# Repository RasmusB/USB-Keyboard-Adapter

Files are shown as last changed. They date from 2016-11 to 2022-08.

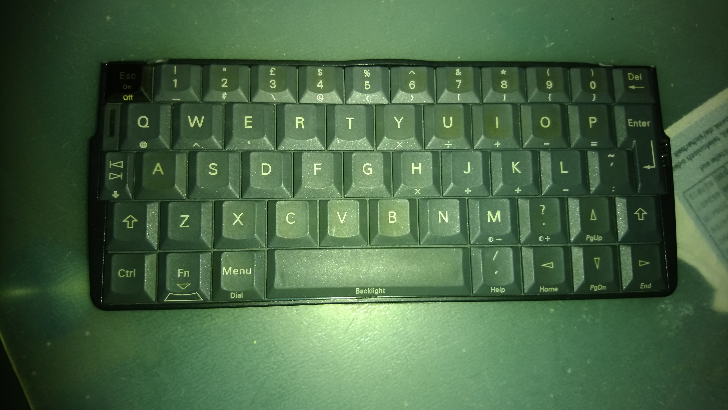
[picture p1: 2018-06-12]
Psion-Keyboard-Firmware/Keymaps/mx5_UK/UK Layout.jpg

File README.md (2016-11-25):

# USB-Keyboard-Adapter

An ATmega32u4 based keyboard controller. This was designed for use with a Psion Series 5mx keyboard, but should work for other keyboards also.

* PCB contains KiCad files for the device itself
* Firmware/Psion-Keyboard-Firmware contains an Arduino sketch for the firmware
* Firmware/ScanTheMatrix is a sketch for scanning the matrix of a keyboard. This is only meant as a tool to map a keyboard with an unknown pinout.

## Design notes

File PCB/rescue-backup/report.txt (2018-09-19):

Info: Backing up file “C:\Users\Rasmus\Dropbox\Projekt\Teknik\USB-Keyboard-Adapter\PCB\sym-lib-table” to file “C:\Users\Rasmus\Dropbox\Projekt\Teknik\USB-Keyboard-Adapter\PCB\rescue-backup\sym-lib-table-2018-09-19-20-54-59”.
Info: Backing up file “C:\Users\Rasmus\Dropbox\Projekt\Teknik\USB-Keyboard-Adapter\PCB\Keyboard.sch” to file “C:\Users\Rasmus\Dropbox\Projekt\Teknik\USB-Keyboard-Adapter\PCB\rescue-backup\Keyboard-2018-09-19-20-54-59.sch”.
Info: Backing up file “C:\Users\Rasmus\Dropbox\Projekt\Teknik\USB-Keyboard-Adapter\PCB\Keyboard.pro” to file “C:\Users\Rasmus\Dropbox\Projekt\Teknik\USB-Keyboard-Adapter\PCB\rescue-backup\Keyboard-2018-09-19-20-54-59.pro”.
Info: Backing up file “C:\Users\Rasmus\Dropbox\Projekt\Teknik\USB-Keyboard-Adapter\PCB\Keyboard-cache.lib” to file “C:\Users\Rasmus\Dropbox\Projekt\Teknik\USB-Keyboard-Adapter\PCB\rescue-backup\Keyboard-cache-2018-09-19-20-54-59.lib”.
Info: Backing up file “C:\Users\Rasmus\Dropbox\Projekt\Teknik\USB-Keyboard-Adapter\PCB\Keyboard-rescue.lib” to file “C:\Users\Rasmus\Dropbox\Projekt\Teknik\USB-Keyboard-Adapter\PCB\rescue-backup\Keyboard-rescue-2018-09-19-20-54-59.lib”.
Info: Backing up file “C:\Users\Rasmus\Dropbox\Projekt\Teknik\USB-Keyboard-Adapter\PCB\Keyboard-rescue.dcm” to file “C:\Users\Rasmus\Dropbox\Projekt\Teknik\USB-Keyboard-Adapter\PCB\rescue-backup\Keyboard-rescue-2018-09-19-20-54-59.dcm”.
Info: Adding library “Keyboard-rescue”, file “${KIPRJMOD}/Keyboard-rescue.lib” to project symbol library table.
Info: Adding library “rbv_adc”, file “C:\Users\Rasmus\Dropbox\Projekt\Teknik\common\kicad-libs\rb-lib\rbv_adc.lib” to project symbol library table.
Info: Adding library “rbv_arduino”, file “C:\Users\Rasmus\Dropbox\Projekt\Teknik\common\kicad-libs\rb-lib\rbv_arduino.lib” to project symbol library table.
Info: Adding library “rbv_beagleBoard”, file “C:\Users\Rasmus\Dropbox\Projekt\Teknik\common\kicad-libs\rb-lib\rbv_beagleBoard.lib” to project symbol library table.
Info: Adding library “rbv_connectors”, file “C:\Users\Rasmus\Dropbox\Projekt\Teknik\common\kicad-libs\rb-lib\rbv_connectors.lib” to project symbol library table.
Info: Adding library “rbv_conversion”, file “C:\Users\Rasmus\Dropbox\Projekt\Teknik\common\kicad-libs\rb-lib\rbv_conversion.lib” to project symbol library table.
Info: Adding library “rbv_dac”, file “C:\Users\Rasmus\Dropbox\Projekt\Teknik\common\kicad-libs\rb-lib\rbv_dac.lib” to project symbol library table.
Info: Adding library “rbv_device”, file “C:\Users\Rasmus\Dropbox\Projekt\Teknik\common\kicad-libs\rb-lib\rbv_device.lib” to project symbol library table.
Info: Adding library “rbv_diodes”, file “C:\Users\Rasmus\Dropbox\Projekt\Teknik\common\kicad-libs\rb-lib\rbv_diodes.lib” to project symbol library table.
Info: Adding library “rbv_display”, file “C:\Users\Rasmus\Dropbox\Projekt\Teknik\common\kicad-libs\rb-lib\rbv_display.lib” to project symbol library table.
Info: Adding library “rbv_drivers”, file “C:\Users\Rasmus\Dropbox\Projekt\Teknik\common\kicad-libs\rb-lib\rbv_drivers.lib” to project symbol library table.
Info: Adding library “rbv_ecu”, file “C:\Users\Rasmus\Dropbox\Projekt\Teknik\common\kicad-libs\rb-lib\rbv_ecu.lib” to project symbol library table.
Info: Adding library “rbv_fpga”, file “C:\Users\Rasmus\Dropbox\Projekt\Teknik\common\kicad-libs\rb-lib\rbv_fpga.lib” to project symbol library table.
Info: Adding library “rbv_freescale”, file “C:\Users\Rasmus\Dropbox\Projekt\Teknik\common\kicad-libs\rb-lib\rbv_freescale.lib” to project symbol library table.
Info: Adding library “rbv_gps”, file “C:\Users\Rasmus\Dropbox\Projekt\Teknik\common\kicad-libs\rb-lib\rbv_gps.lib” to project symbol library table.
Info: Adding library “rbv_gumstix”, file “C:\Users\Rasmus\Dropbox\Projekt\Teknik\common\kicad-libs\rb-lib\rbv_gumstix.lib” to project symbol library table.
Info: Adding library “rbv_intel”, file “C:\Users\Rasmus\Dropbox\Projekt\Teknik\common\kicad-libs\rb-lib\rbv_intel.lib” to project symbol library table.
Info: Adding library “rbv_interface”, file “C:\Users\Rasmus\Dropbox\Projekt\Teknik\common\kicad-libs\rb-lib\rbv_interface.lib” to project symbol library table.
Info: Adding library “rbv_linear”, file “C:\Users\Rasmus\Dropbox\Projekt\Teknik\common\kicad-libs\rb-lib\rbv_linear.lib” to project symbol library table.
Info: Adding library “rbv_logic”, file “C:\Users\Rasmus\Dropbox\Projekt\Teknik\common\kicad-libs\rb-lib\rbv_logic.lib” to project symbol library table.
Info: Adding library “rbv_logos”, file “C:\Users\Rasmus\Dropbox\Projekt\Teknik\common\kicad-libs\rb-lib\rbv_logos.lib” to project symbol library table.
Info: Adding library “rbv_mcu”, file “C:\Users\Rasmus\Dropbox\Projekt\Teknik\common\kicad-libs\rb-lib\rbv_mcu.lib” to project symbol library table.
Info: Adding library “rbv_memory”, file “C:\Users\Rasmus\Dropbox\Projekt\Teknik\common\kicad-libs\rb-lib\rbv_memory.lib” to project symbol library table.
Info: Adding library “rbv_mosfet”, file “C:\Users\Rasmus\Dropbox\Projekt\Teknik\common\kicad-libs\rb-lib\rbv_mosfet.lib” to project symbol library table.
Info: Adding library “rbv_pcb_extras”, file “C:\Users\Rasmus\Dropbox\Projekt\Teknik\common\kicad-libs\rb-lib\rbv_pcb_extras.lib” to project symbol library table.
Info: Adding library “rbv_power”, file “C:\Users\Rasmus\Dropbox\Projekt\Teknik\common\kicad-libs\rb-lib\rbv_power.lib” to project symbol library table.
Info: Adding library “rbv_ref”, file “C:\Users\Rasmus\Dropbox\Projekt\Teknik\common\kicad-libs\rb-lib\rbv_ref.lib” to project symbol library table.
Info: Adding library “rbv_regul”, file “C:\Users\Rasmus\Dropbox\Projekt\Teknik\common\kicad-libs\rb-lib\rbv_regul.lib” to project symbol library table.
Info: Adding library “rbv_rpi”, file “C:\Users\Rasmus\Dropbox\Projekt\Teknik\common\kicad-libs\rb-lib\rbv_rpi.lib” to project symbol library table.
Info: Adding library “rbv_sensors”, file “C:\Users\Rasmus\Dropbox\Projekt\Teknik\common\kicad-libs\rb-lib\rbv_sensors.lib” to project symbol library table.
Info: Adding library “rbv_switches”, file “C:\Users\Rasmus\Dropbox\Projekt\Teknik\common\kicad-libs\rb-lib\rbv_switches.lib” to project symbol library table.
Info: Adding library “rbv_temp”, file “C:\Users\Rasmus\Dropbox\Projekt\Teknik\common\kicad-libs\rb-lib\rbv_temp.lib” to project symbol library table.
Info: Adding library “rbv_transistor”, file “C:\Users\Rasmus\Dropbox\Projekt\Teknik\common\kicad-libs\rb-lib\rbv_transistor.lib” to project symbol library table.
Info: Adding library “rbv_keyboard”, file “C:\Users\Rasmus\Dropbox\Projekt\Teknik\common\kicad-libs\rb-lib\rbv_keyboard.lib” to project symbol library table.
Info: Adding library “transistors”, file “${KICAD_SYMBOL_DIR}/transistors.lib” to project symbol library table.
Info: Adding library “conn”, file “${KICAD_SYMBOL_DIR}/conn.lib” to project symbol library table.
Info: Adding library “linear”, file “${KICAD_SYMBOL_DIR}/linear.lib” to project symbol library table.
Info: Adding library “regul”, file “${KICAD_SYMBOL_DIR}/regul.lib” to project symbol library table.
Info: Adding library “cmos4000”, file “${KICAD_SYMBOL_DIR}/cmos4000.lib” to project symbol library table.
Info: Adding library “adc-dac”, file “${KICAD_SYMBOL_DIR}/adc-dac.lib” to project symbol library table.
Info: Adding library “memory”, file “${KICAD_SYMBOL_DIR}/memory.lib” to project symbol library table.
Info: Adding library “xilinx”, file “${KICAD_SYMBOL_DIR}/xilinx.lib” to project symbol library table.
Info: Adding library “microcontrollers”, file “${KICAD_SYMBOL_DIR}/microcontrollers.lib” to project symbol library table.
Info: Adding library “dsp”, file “${KICAD_SYMBOL_DIR}/dsp.lib” to project symbol library table.
Info: Adding library “microchip”, file “${KICAD_SYMBOL_DIR}/microchip.lib” to project symbol library table.
Info: Adding library “analog_switches”, file “${KICAD_SYMBOL_DIR}/analog_switches.lib” to project symbol library table.
Info: Adding library “motorola”, file “${KICAD_SYMBOL_DIR}/motorola.lib” to project symbol library table.
Info: Adding library “texas”, file “${KICAD_SYMBOL_DIR}/texas.lib” to project symbol library table.
Info: Adding library “intel”, file “${KICAD_SYMBOL_DIR}/intel.lib” to project symbol library table.
Info: Adding library “digital-audio”, file “${KICAD_SYMBOL_DIR}/digital-audio.lib” to project symbol library table.
Info: Adding library “philips”, file “${KICAD_SYMBOL_DIR}/philips.lib” to project symbol library table.
Info: Adding library “display”, file “${KICAD_SYMBOL_DIR}/display.lib” to project symbol library table.
Info: Adding library “cypress”, file “${KICAD_SYMBOL_DIR}/cypress.lib” to project symbol library table.
Info: Adding library “siliconi”, file “${KICAD_SYMBOL_DIR}/siliconi.lib” to project symbol library table.
Info: Adding library “opto”, file “${KICAD_SYMBOL_DIR}/opto.lib” to project symbol library table.
Info: Adding library “atmel”, file “${KICAD_SYMBOL_DIR}/atmel.lib” to project symbol library table.
Info: Adding library “contrib”, file “${KICAD_SYMBOL_DIR}/contrib.lib” to project symbol library table.
Info: Adding library “valves”, file “${KICAD_SYMBOL_DIR}/valves.lib” to project symbol library table.
Symbol “KEYBOARD-PSION-5MX” mapped to symbol library “rbv_keyboard”.
Symbol “ATMEGA32U4-QFN44” mapped to symbol library “rbv_mcu”.
Symbol “+5V” mapped to symbol library “power”.
Symbol “GND” mapped to symbol library “power”.
Symbol “C” mapped to symbol library “Device”.
Symbol “C” mapped to symbol library “Device”.
Symbol “C” mapped to symbol library “Device”.
Symbol “C” mapped to symbol library “Device”.
Symbol “C” mapped to symbol library “Device”.
Symbol “C” mapped to symbol library “Device”.
Symbol “+5V” mapped to symbol library “power”.
Symbol “+5V” mapped to symbol library “power”.
Symbol “+5V” mapped to symbol library “power”.
Symbol “GND” mapped to symbol library “power”.
Symbol “C” mapped to symbol library “Device”.
Symbol “C” mapped to symbol library “Device”.
Symbol “GND” mapped to symbol library “power”.
Symbol “CRYSTAL-4pin” mapped to symbol library “rbv_device”.
Symbol “C” mapped to symbol library “Device”.
Symbol “C” mapped to symbol library “Device”.
Symbol “GND” mapped to symbol library “power”.
Symbol “GND” mapped to symbol library “power”.
Symbol “C” mapped to symbol library “Device”.
Symbol “R” mapped to symbol library “Device”.
Symbol “R” mapped to symbol library “Device”.
Symbol “+5V” mapped to symbol library “power”.
Symbol “R” mapped to symbol library “Device”.
Symbol “+5V” mapped to symbol library “power”.
Symbol “ATMEL_ISP-6P” mapped to symbol library “rbv_mcu”.
Symbol “+5V” mapped to symbol library “power”.
Symbol “GND” mapped to symbol library “power”.
Symbol “USB_OTG-RESCUE-Keyboard” mapped to symbol library “Keyboard-rescue”.
Symbol “R” mapped to symbol library “Device”.
Symbol “C” mapped to symbol library “Device”.
Symbol “GNDPWR” mapped to symbol library “Keyboard-rescue”.
Symbol “Led_Small” mapped to symbol library “Keyboard-rescue”.
Symbol “R_Small” mapped to symbol library “Device”.
Symbol “GND” mapped to symbol library “power”.
Symbol “SW_PUSH” mapped to symbol library “Keyboard-rescue”.
Symbol “GND” mapped to symbol library “power”.
Symbol “GND” mapped to symbol library “power”.
Symbol “VBUS” mapped to symbol library “rbv_power”.
Symbol “F_Small” mapped to symbol library “Keyboard-rescue”.
Info: Symbol library table mapping complete!

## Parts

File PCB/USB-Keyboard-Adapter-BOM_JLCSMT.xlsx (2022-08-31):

Comment | Designator | Footprint | JLCPCB Part #（optional）
1µF | C1, C9 | C_0402 | C52923
100nF | C2, C3, C4, C5, C6, C7, C8 | C_0402 | C1525
6.2pF | C10, C11 | C_0402 | C325456
4.7nF | C12 | C_0402 | C1538
STATUS LED | D1 | LED_0402 | C965790
500mA Polyfuse | F1 | FUSE_0603 | C207017
22p FPC connector | KB1 | 22p FPC | C262275
USB Micro B | P1 | USB Micro B | C132563
10k | R1 | R_0402 | C25744
22R | R2, R3 | R_0402 | C25092
1M | R4 | R_0402 | C26083
1k | R5 | R_0402 | C11702
RESET BUTTON | SW1 | Switch | C115358
ATMEGA32U4-MU | U1 | QFN44 | C112161
16MHz | Y1 | 2.5x2.0mm 4pin | C1986789

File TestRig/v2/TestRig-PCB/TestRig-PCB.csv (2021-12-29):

Reference | Value | Footprint | Datasheet | MPN | Manufacturer
MOD101 | STM32_BLUE_PILL | BluePill:STM32F103C8T6-ARM-BOARD
J101 | AVR-ISP-6 | Connector_IDC:IDC-Header_2x03_P2.54mm_Vertical | ~ | 87834-0619 | Molex
J102 | AVR-ISP-10 | Connector_IDC:IDC-Header_2x05_P2.54mm_Vertical | ~ | 70246-1001 | Molex
R102 | 4k7 | Resistor_SMD:R_0603_1608Metric | ~ | CR0603-JW-472ELF | Bourns
R101 | 4k7 | Resistor_SMD:R_0603_1608Metric | ~ | CR0603-JW-472ELF | Bourns
R103 | 10k | Resistor_SMD:R_0603_1608Metric | ~ | CR0603-JW-103ELF | Bourns
R104 | 10k | Resistor_SMD:R_0603_1608Metric | ~ | CR0603-JW-103ELF | Bourns
H101 | M3 | MountingHole:MountingHole_3.2mm_M3 | ~
H102 | M3 | MountingHole:MountingHole_3.2mm_M3 | ~
H103 | M3 | MountingHole:MountingHole_3.2mm_M3 | ~
H104 | M3 | MountingHole:MountingHole_3.2mm_M3 | ~
H105 | M3 | MountingHole:MountingHole_3.2mm_M3 | ~
H106 | M3 | MountingHole:MountingHole_3.2mm_M3 | ~
JIG_OUTLINE_1 | TEST_JIG | USB-Keyboard:TestJig
REG101 | eC_REG | PCB Extras:eC-Registration
REG102 | eC_REG | PCB Extras:eC-Registration
TP206 | VBUS | Pogo:Pogo_P50_Bottom | ~
TP207 | GND | Pogo:Pogo_P50_Bottom | ~
TP201 | RESET | Pogo:Pogo_P50_Bottom | ~
TP202 | SCK | Pogo:Pogo_P50_Bottom | ~
TP204 | MISO | Pogo:Pogo_P50_Bottom | ~
TP203 | MOSI | Pogo:Pogo_P50_Bottom | ~
R201 | 10k 0.1% | Resistor_SMD:R_0603_1608Metric | ~ | ERA-3AEB103V | Panasonic
R202 | 10k 0.1% | Resistor_SMD:R_0603_1608Metric | ~ | ERA-3AEB103V | Panasonic
DUT201 | DUT_OUTLINE | USB-Keyboard:USB_KEYBOARD_ADAPTER_V1.22_DUMMY
TP205 | VTARGET | Pogo:Pogo_P50_Bottom | ~
J201 | DUT_CONN | Connector_FFC-FPC:Hirose_FH12-22S-0.5SH_1x22-1MP_P0.50mm_Horizontal |  | FH12A-22S-0.5SH(55) | Hirose
C201 | 100n | Capacitor_SMD:C_0603_1608Metric | ~ | C0603C104Z3VACTU | KEMET
U201 | TCA6424A | Package_DFN_QFN:QFN-32-1EP_5x5mm_P0.5mm_EP3.1x3.1mm | https://www.ti.com/lit/gpn/tca6424a | TCA6424ARGJR | Texas Instruments
C202 | 100n | Capacitor_SMD:C_0603_1608Metric | ~ | C0603C104Z3VACTU | KEMET
R203 | 4k7 | Resistor_SMD:R_0603_1608Metric | ~ | CR0603-JW-472ELF | Bourns
R204 | 270R | Resistor_SMD:R_0603_1608Metric |  | CRGCQ0603F270R | TE Connecitivity
LED201 | RED | LED_SMD:LED_0603_1608Metric | https://datasheet.octopart.com/APT1608SRCPRV-Kingbright-datasheet-12598008.pdf | APT1608SRCPRV | Kingbright
R205 | 270R | Resistor_SMD:R_0603_1608Metric |  | CRGCQ0603F270R | TE Connecitivity
LED202 | ORNG | LED_SMD:LED_0603_1608Metric | https://datasheet.octopart.com/APT1608SECK-Kingbright-datasheet-8326367.pdf | APT1608SECK | Kingbright
R206 | 270R | Resistor_SMD:R_0603_1608Metric |  | CRGCQ0603F270R | TE Connecitivity
LED203 | YLW | LED_SMD:LED_0603_1608Metric | https://datasheet.octopart.com/APT1608SYCK-Kingbright-datasheet-108048836.pdf | APT1608SYCK | Kingbright
R207 | 270R | Resistor_SMD:R_0603_1608Metric |  | CRGCQ0603F270R | TE Connecitivity
LED204 | GRN | LED_SMD:LED_0603_1608Metric | https://datasheet.octopart.com/APT1608CGCK-Kingbright-datasheet-12518645.pdf | APT1608CGCK | Kingbright
U301 | TS5A3357 | Package_SO:VSSOP-8_2.3x2mm_P0.5mm | https://www.ti.com/lit/ds/symlink/ts5a3357.pdf | TS5A3357DCUR | Texas Instruments
C302 | 100n | Capacitor_SMD:C_0603_1608Metric | ~ | C0603C104Z3VACTU | KEMET
C303 | 100n | Capacitor_SMD:C_0603_1608Metric | ~ | C0603C104Z3VACTU | KEMET
C304 | 100n | Capacitor_SMD:C_0603_1608Metric | ~ | C0603C104Z3VACTU | KEMET
C305 | 100n | Capacitor_SMD:C_0603_1608Metric | ~ | C0603C104Z3VACTU | KEMET
U302 | TS5A3357 | Package_SO:VSSOP-8_2.3x2mm_P0.5mm | https://www.ti.com/lit/ds/symlink/ts5a3357.pdf | TS5A3357DCUR | Texas Instruments
U303 | TS5A3357 | Package_SO:VSSOP-8_2.3x2mm_P0.5mm | https://www.ti.com/lit/ds/symlink/ts5a3357.pdf | TS5A3357DCUR | Texas Instruments
U304 | TS5A3357 | Package_SO:VSSOP-8_2.3x2mm_P0.5mm | https://www.ti.com/lit/ds/symlink/ts5a3357.pdf | TS5A3357DCUR | Texas Instruments
U305 | TS5A3357 | Package_SO:VSSOP-8_2.3x2mm_P0.5mm | https://www.ti.com/lit/ds/symlink/ts5a3357.pdf | TS5A3357DCUR | Texas Instruments
C301 | 100n | Capacitor_SMD:C_0603_1608Metric | ~ | C0603C104Z3VACTU | KEMET
TP406 | VBUS | Pogo:Pogo_P50_Bottom | ~
TP407 | GND | Pogo:Pogo_P50_Bottom | ~
TP401 | RESET | Pogo:Pogo_P50_Bottom | ~
TP402 | SCK | Pogo:Pogo_P50_Bottom | ~
TP404 | MISO | Pogo:Pogo_P50_Bottom | ~
TP403 | MOSI | Pogo:Pogo_P50_Bottom | ~
R401 | 10k 0.1% | Resistor_SMD:R_0603_1608Metric | ~ | ERA-3AEB103V | Panasonic
R402 | 10k 0.1% | Resistor_SMD:R_0603_1608Metric | ~ | ERA-3AEB103V | Panasonic
DUT401 | DUT_OUTLINE | USB-Keyboard:USB_KEYBOARD_ADAPTER_V1.22_DUMMY
TP405 | VTARGET | Pogo:Pogo_P50_Bottom | ~
J401 | DUT_CONN | Connector_FFC-FPC:Hirose_FH12-22S-0.5SH_1x22-1MP_P0.50mm_Horizontal |  | FH12A-22S-0.5SH(55) | Hirose
C401 | 100n | Capacitor_SMD:C_0603_1608Metric | ~ | C0603C104Z3VACTU | KEMET
U401 | TCA6424A | Package_DFN_QFN:QFN-32-1EP_5x5mm_P0.5mm_EP3.1x3.1mm | https://www.ti.com/lit/gpn/tca6424a | TCA6424ARGJR | Texas Instruments
C402 | 100n | Capacitor_SMD:C_0603_1608Metric | ~ | C0603C104Z3VACTU | KEMET
R403 | 4k7 | Resistor_SMD:R_0603_1608Metric | ~ | CR0603-JW-472ELF | Bourns
R404 | 270R | Resistor_SMD:R_0603_1608Metric |  | CRGCQ0603F270R | TE Connecitivity
LED401 | RED | LED_SMD:LED_0603_1608Metric | https://datasheet.octopart.com/APT1608SRCPRV-Kingbright-datasheet-12598008.pdf | APT1608SRCPRV | Kingbright
R405 | 270R | Resistor_SMD:R_0603_1608Metric |  | CRGCQ0603F270R | TE Connecitivity
LED402 | ORNG | LED_SMD:LED_0603_1608Metric | https://datasheet.octopart.com/APT1608SECK-Kingbright-datasheet-8326367.pdf | APT1608SECK | Kingbright
R406 | 270R | Resistor_SMD:R_0603_1608Metric |  | CRGCQ0603F270R | TE Connecitivity
LED403 | YLW | LED_SMD:LED_0603_1608Metric | https://datasheet.octopart.com/APT1608SYCK-Kingbright-datasheet-108048836.pdf | APT1608SYCK | Kingbright
R407 | 270R | Resistor_SMD:R_0603_1608Metric |  | CRGCQ0603F270R | TE Connecitivity
LED404 | GRN | LED_SMD:LED_0603_1608Metric | https://datasheet.octopart.com/APT1608CGCK-Kingbright-datasheet-12518645.pdf | APT1608CGCK | Kingbright
TP506 | VBUS | Pogo:Pogo_P50_Bottom | ~
TP507 | GND | Pogo:Pogo_P50_Bottom | ~
TP501 | RESET | Pogo:Pogo_P50_Bottom | ~
TP502 | SCK | Pogo:Pogo_P50_Bottom | ~
TP504 | MISO | Pogo:Pogo_P50_Bottom | ~
TP503 | MOSI | Pogo:Pogo_P50_Bottom | ~
R501 | 10k 0.1% | Resistor_SMD:R_0603_1608Metric | ~ | ERA-3AEB103V | Panasonic
R502 | 10k 0.1% | Resistor_SMD:R_0603_1608Metric | ~ | ERA-3AEB103V | Panasonic
DUT501 | DUT_OUTLINE | USB-Keyboard:USB_KEYBOARD_ADAPTER_V1.22_DUMMY
TP505 | VTARGET | Pogo:Pogo_P50_Bottom | ~
J501 | DUT_CONN | Connector_FFC-FPC:Hirose_FH12-22S-0.5SH_1x22-1MP_P0.50mm_Horizontal |  | FH12A-22S-0.5SH(55) | Hirose
C501 | 100n | Capacitor_SMD:C_0603_1608Metric | ~ | C0603C104Z3VACTU | KEMET
U501 | TCA6424A | Package_DFN_QFN:QFN-32-1EP_5x5mm_P0.5mm_EP3.1x3.1mm | https://www.ti.com/lit/gpn/tca6424a | TCA6424ARGJR | Texas Instruments
C502 | 100n | Capacitor_SMD:C_0603_1608Metric | ~ | C0603C104Z3VACTU | KEMET
R503 | 4k7 | Resistor_SMD:R_0603_1608Metric | ~ | CR0603-JW-472ELF | Bourns
R504 | 270R | Resistor_SMD:R_0603_1608Metric |  | CRGCQ0603F270R | TE Connecitivity
LED501 | RED | LED_SMD:LED_0603_1608Metric | https://datasheet.octopart.com/APT1608SRCPRV-Kingbright-datasheet-12598008.pdf | APT1608SRCPRV | Kingbright
R505 | 270R | Resistor_SMD:R_0603_1608Metric |  | CRGCQ0603F270R | TE Connecitivity
LED502 | ORNG | LED_SMD:LED_0603_1608Metric | https://datasheet.octopart.com/APT1608SECK-Kingbright-datasheet-8326367.pdf | APT1608SECK | Kingbright
R506 | 270R | Resistor_SMD:R_0603_1608Metric |  | CRGCQ0603F270R | TE Connecitivity
LED503 | YLW | LED_SMD:LED_0603_1608Metric | https://datasheet.octopart.com/APT1608SYCK-Kingbright-datasheet-108048836.pdf | APT1608SYCK | Kingbright
R507 | 270R | Resistor_SMD:R_0603_1608Metric |  | CRGCQ0603F270R | TE Connecitivity
LED504 | GRN | LED_SMD:LED_0603_1608Metric | https://datasheet.octopart.com/APT1608CGCK-Kingbright-datasheet-12518645.pdf | APT1608CGCK | Kingbright

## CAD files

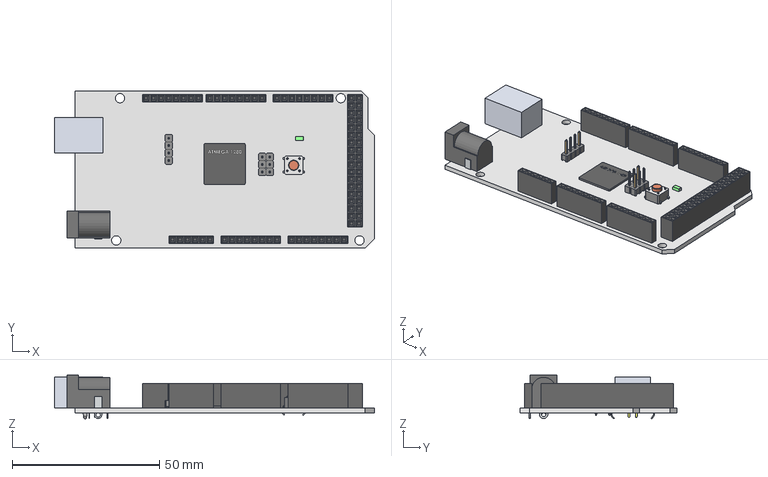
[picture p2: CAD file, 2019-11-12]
TestRig/v2/TestRig-PCB/Footprints/STEP/ArduinoMega2560R3.step
108.6 x 53.2 x 14.9 mm

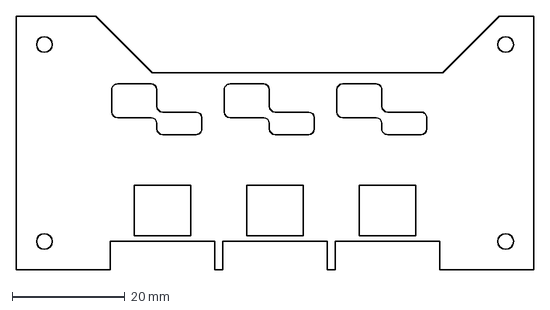
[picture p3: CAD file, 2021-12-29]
TestRig/v2/TestRig-PCB/Footprints/Test Jig v12 outline.dxf
92.0 x 45.0 mm

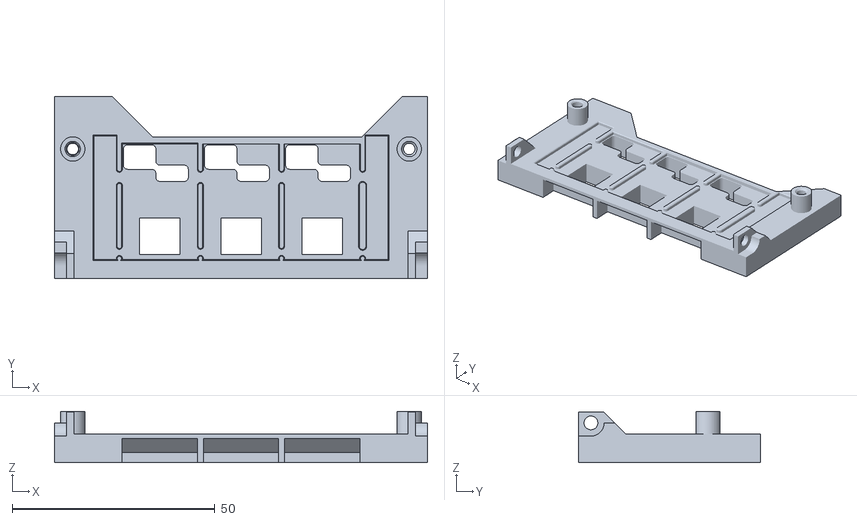
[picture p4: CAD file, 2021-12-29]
TestRig/v2/TestRig-PCB/Test Jig Base v10.stl
92.0 x 45.0 x 12.6

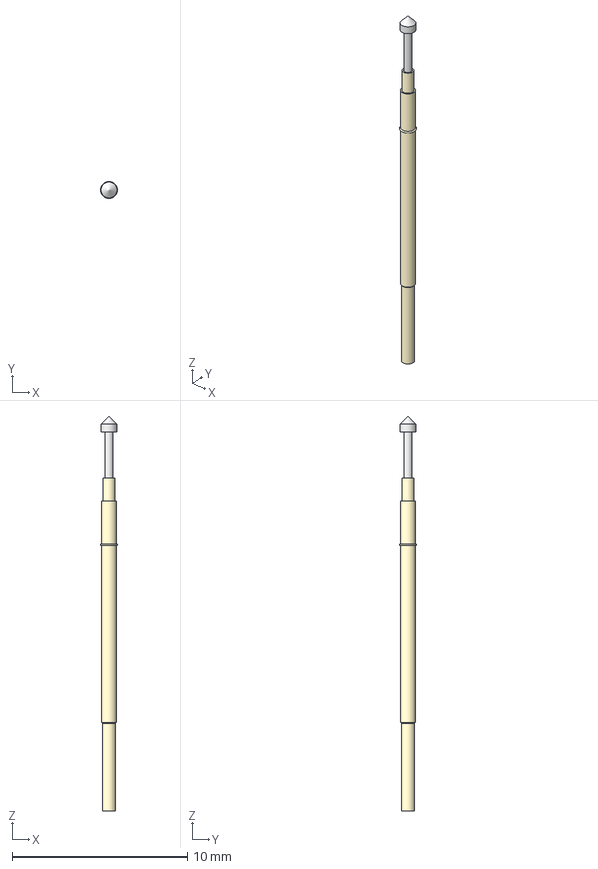
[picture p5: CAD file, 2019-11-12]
TestRig/v2/TestRig-PCB/Footprints/STEP/P50-T2.step
0.97 x 0.97 x 22.6 mm
P50 Receptacle
P50 pin body_1
T2 tip

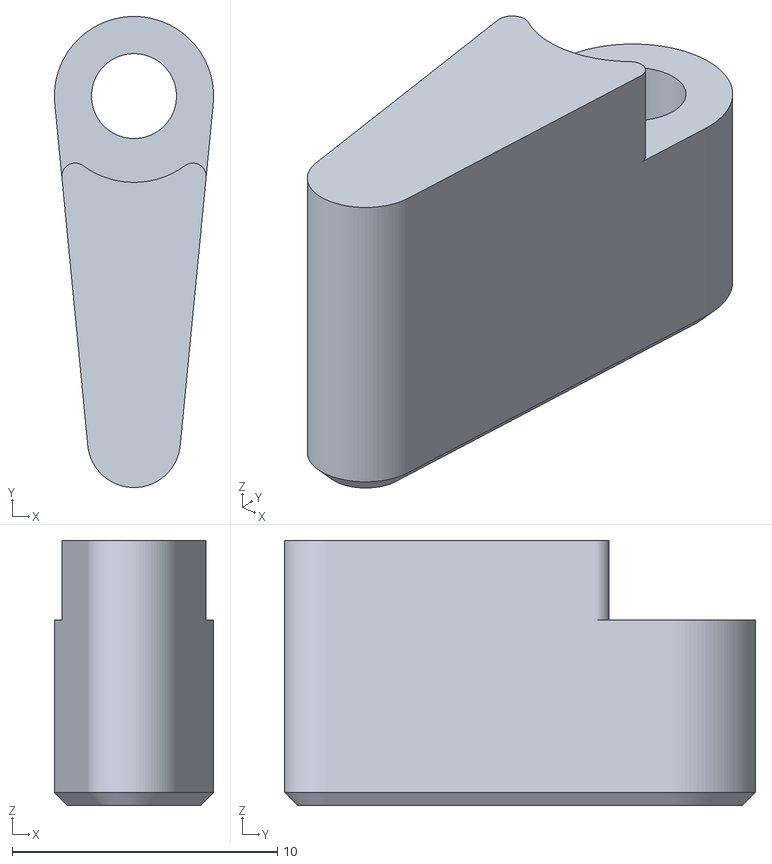
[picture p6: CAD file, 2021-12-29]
TestRig/v2/TestRig-PCB/Lock v10.stl
6.00 x 17.7 x 10.0

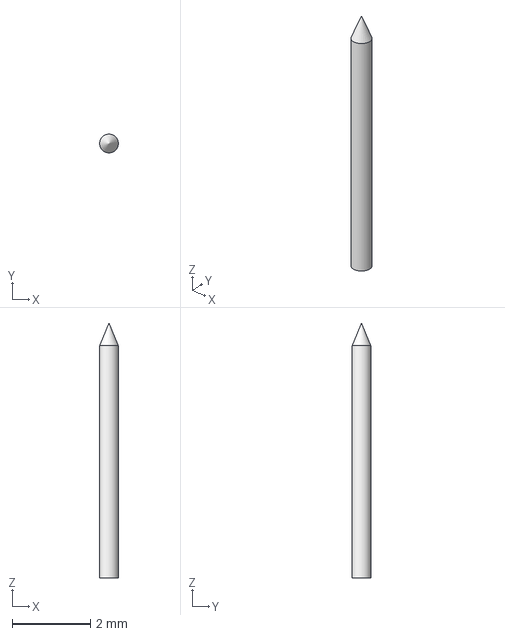
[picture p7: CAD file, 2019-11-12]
TestRig/v2/TestRig-PCB/Footprints/STEP/P50-B1-Tip.step
0.48 x 0.48 x 6.50 mm

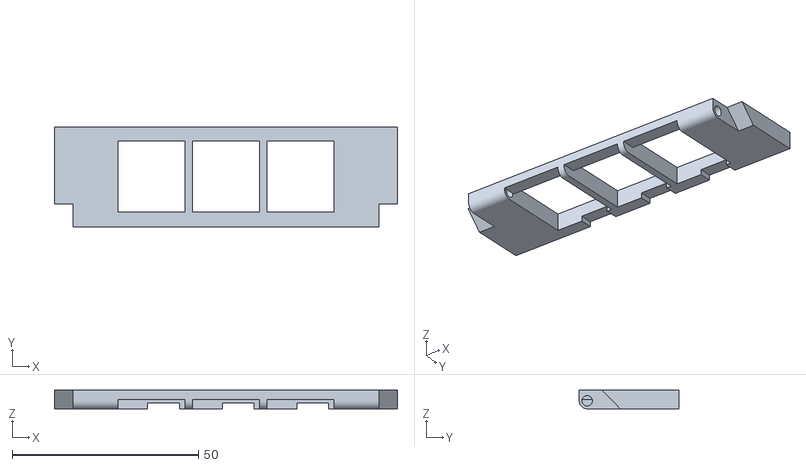
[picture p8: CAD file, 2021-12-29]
TestRig/v2/TestRig-PCB/Test Jig Lid v10.stl
92.0 x 26.7 x 5.00

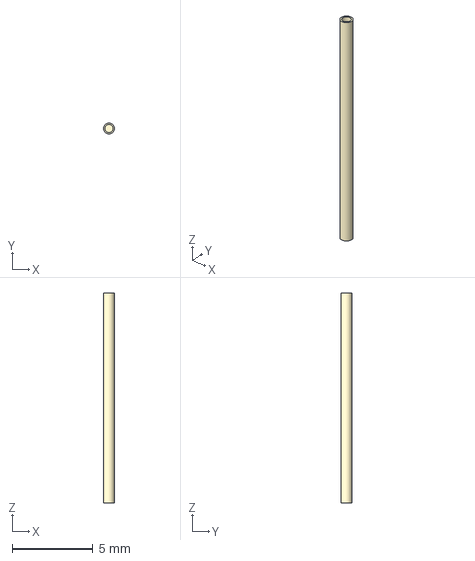
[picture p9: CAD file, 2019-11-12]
TestRig/v2/TestRig-PCB/Footprints/STEP/P50-Body.step
0.68 x 0.68 x 13.0 mm

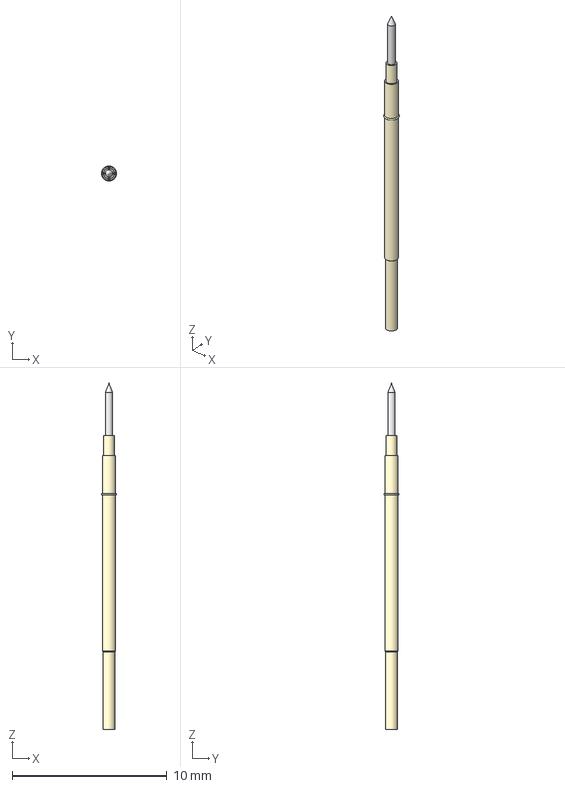
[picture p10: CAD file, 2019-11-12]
TestRig/v2/TestRig-PCB/Footprints/STEP/P50-B1.step
0.97 x 0.97 x 22.4 mm

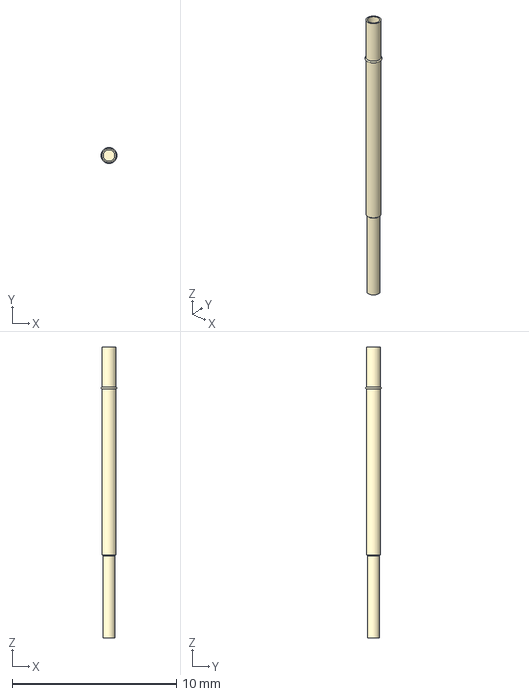
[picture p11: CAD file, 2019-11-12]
TestRig/v2/TestRig-PCB/Footprints/STEP/P50-S1-Receptacle.step
0.97 x 0.97 x 17.7 mm

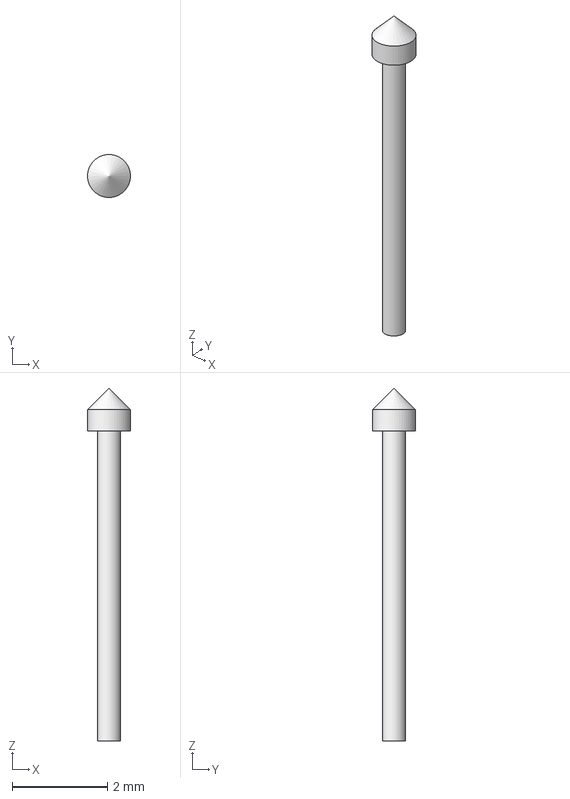
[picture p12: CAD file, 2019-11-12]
TestRig/v2/TestRig-PCB/Footprints/STEP/P50-T2-Tip.step
0.9 x 0.9 x 7.40 mm

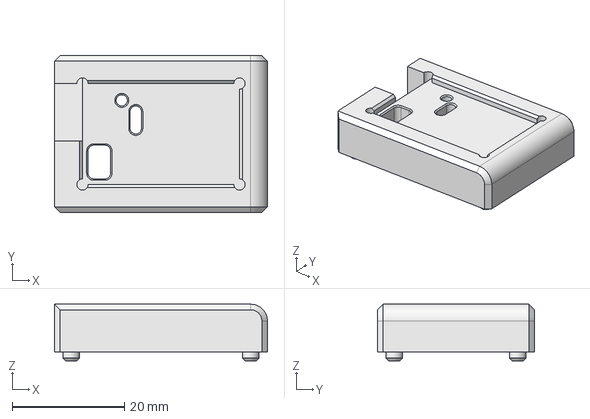
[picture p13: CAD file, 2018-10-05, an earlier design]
TestRig/v1/Test jig.FCStd
38.0 x 28.0 x 10.1 mm

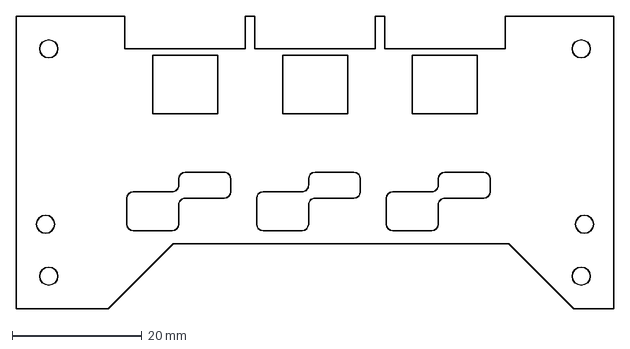
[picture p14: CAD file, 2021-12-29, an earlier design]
TestRig/v2/TestRig-PCB/Footprints/Test Jig v10 outline.dxf
92.0 x 45.0 mm

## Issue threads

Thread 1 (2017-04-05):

Wrong pinout used in Arduino sketches

RasmusB, 2017-04-05:
The pinout used in the Arduino sketches does not match the actual pinout of the v1.1 boards. This needs to be updated.

RasmusB, 2017-04-05:
Seems to work now.

Closed 2017-04-05.

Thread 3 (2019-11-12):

iPhone reports incorrect current draw

RasmusB, 2019-11-12:
From a user:
"It works perfectly with my Mac and iPad Pro using a usb c adapter, but with my iPhone and a lightning to USB adapter I get the message Arduino draws too much power."

The same user can use the adapter on his Mac and iPad Pro without issue, so it seems the iPhone is more agressive with the current limitation than a proper USB port. SInce it is a "lightning" port and strictly not USB, they might not follow the USB standard fully.

RasmusB, 2019-11-12:
There is a fix that requires a change in the core Arduino libraries. I tried implementing that in board.h

`#undef D_CONFIG
#define D_CONFIG(_totalLength,_interfaces) \
    { 9, 2, _totalLength,_interfaces, 1, 0, USB_CONFIG_BUS_POWERED | USB_CONFIG_REMOTE_WAKEUP, USB_CONFIG_POWER_MA(100) }`

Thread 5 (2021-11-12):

Project status

nulani38728, 2021-11-12:
Hi, is this project still active and are the PCB designs up to date?  I'm wondering if the files in PCB/ can be sent off for printing as-is, or whether you made some additional modifications to the finished version.

RasmusB, 2021-11-14:
Hello,

the production files are up to date, you can use them as-is.

Closed 2021-11-14.

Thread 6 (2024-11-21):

Keyboard LED

Jonson26, 2024-11-21:
Is there a way to somehow control the keyboard LED?
Either as a caps lock indicator or something custom?

RasmusB, 2024-11-22:
The keyboard itself does not have an LED - at least on the keyboards I have seen. There is a hole and a lens on the keyboard, meant for an LED on the motherboard to shine through. So basically you'll need to add your own LED somehow.

Closed 2024-11-22.

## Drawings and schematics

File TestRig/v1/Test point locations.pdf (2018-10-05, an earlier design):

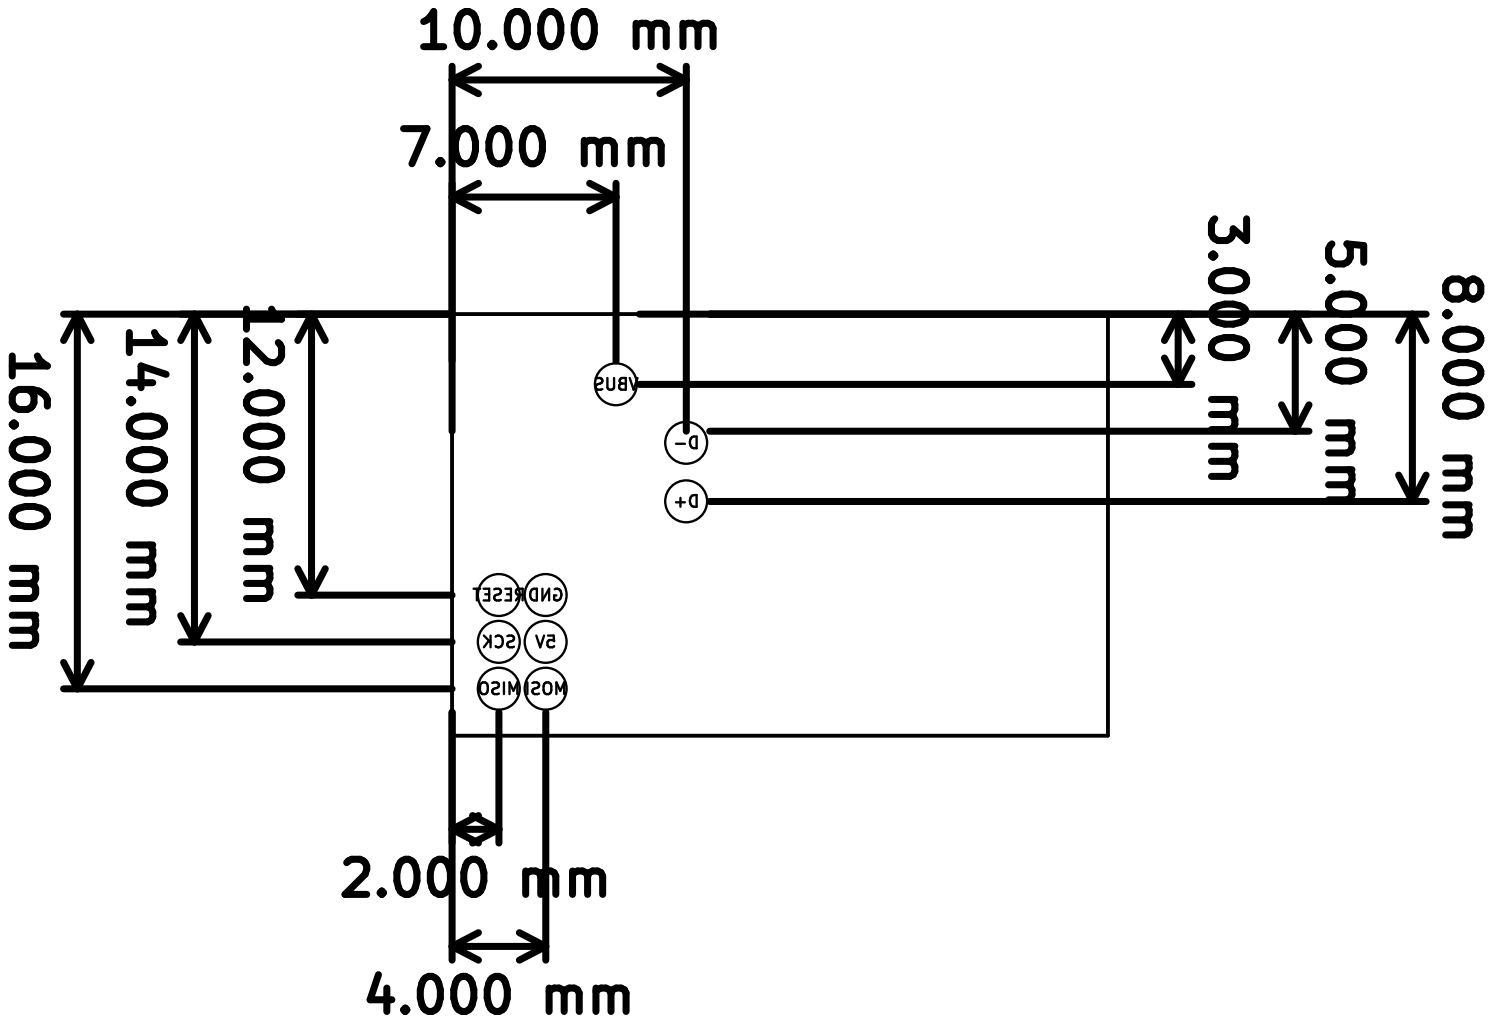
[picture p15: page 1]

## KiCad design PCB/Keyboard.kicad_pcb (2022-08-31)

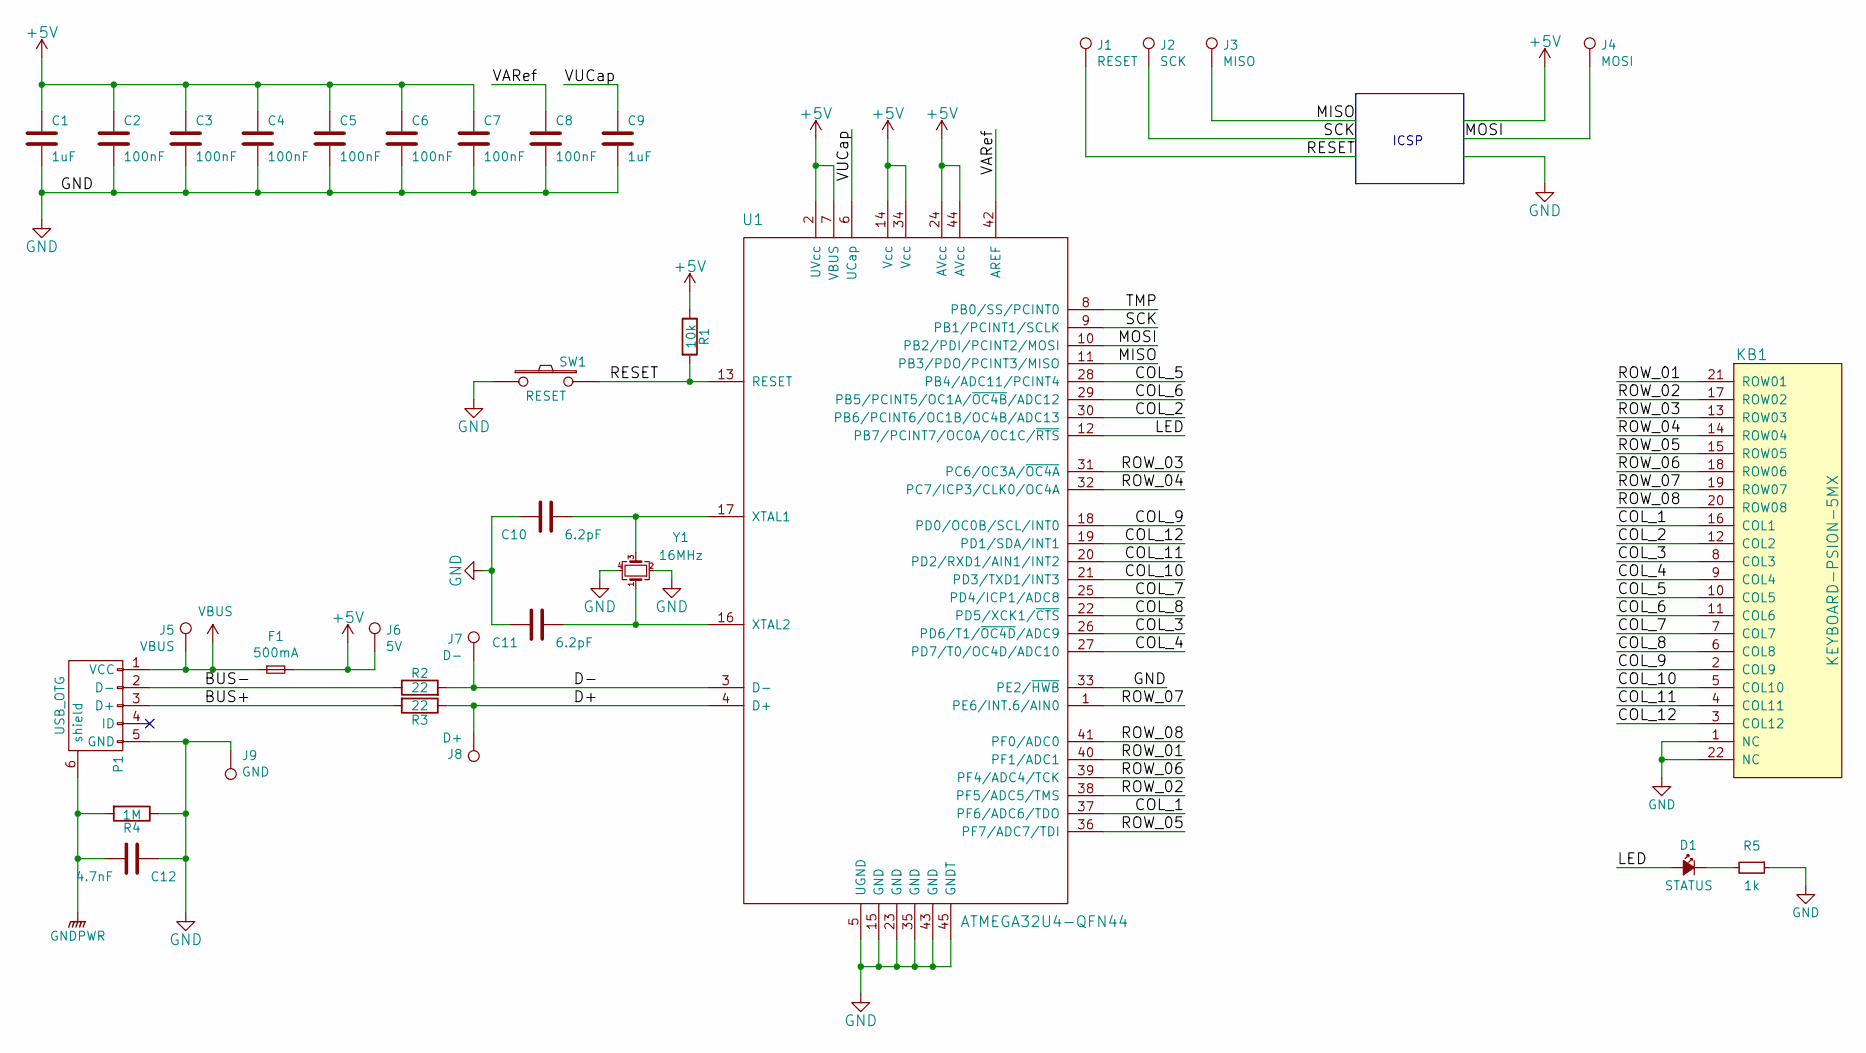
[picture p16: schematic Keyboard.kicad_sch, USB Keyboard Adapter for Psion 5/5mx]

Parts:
C1, C9: 1uF; C_0402_1005Metric; MPN CL05A105KA5NQNC; JLCPCB C52923
C2, C3, C4, C5, C6, C7, C8: 100nF; C_0402_1005Metric; MPN CL05B104KO5NNNC; JLCPCB C1525
C10, C11: 6.2pF; C_0402_1005Metric; MPN CC0402CRNPO9BN6R2; JLCPCB C325456
C12: 4.7nF; C_0402_1005Metric; MPN 0402B472K500NT; JLCPCB C1538
D1: STATUS; LED_0402_1005Metric; MPN XL-1005SURC; JLCPCB C965790
F1: 500mA; Fuse_0603_1608Metric; MPN 0603L100SLYR; JLCPCB C207017
J1: RESET; TESTPOINT-1mm-NO_TEXT
J2: SCK; TESTPOINT-1mm-NO_TEXT
J3: MISO; TESTPOINT-1mm-NO_TEXT
J4: MOSI; TESTPOINT-1mm-NO_TEXT
J5: VBUS; TESTPOINT-1mm-NO_TEXT
J6: 5V; TESTPOINT-1mm-NO_TEXT
J7: D-; TESTPOINT-1mm-NO_TEXT
J8: D+; TESTPOINT-1mm-NO_TEXT
J9: GND; TESTPOINT-1mm-NO_TEXT
KB1: KEYBOARD-PSION-5MX; FPC_22p-JUSHUO_AFC01-S22FCC-00; MPN AFC01-S22FCC-00; JLCPCB C262275
P1: USB_OTG; USB_Micro-B_Amphenol_10118194_Horizontal; MPN 10118194-0001LF; JLCPCB C132563
R1: 10k; R_0402_1005Metric; MPN 0402WGF1002TCE; JLCPCB C25744
R2, R3: 22; R_0402_1005Metric; MPN 0402WGF220JTCE; JLCPCB C25092
R4: 1M; R_0402_1005Metric; MPN 0402WGF1004TCE; JLCPCB C26083
R5: 1k; R_0402_1005Metric; MPN 0402WGF1001TCE; JLCPCB C11702
SW1: RESET; ALPS-SKRMAAE010; MPN SKRMAAE010; JLCPCB C115358
U1: ATMEGA32U4-QFN44; QFN-44-1EP_7x7mm_P0.5mm_EP5.2x5.2mm; MPN ATMEGA32U4-MU; JLCPCB C112161
Y1: 16MHz; Crystal_SMD_Abracon_ABM10-4Pin_2.5x2.0mm; MPN ABM10W-16.0000MHZ-8-D1X-T3; JLCPCB C1986789

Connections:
+5V: C1.1, C2.1, C3.1, C4.1, C5.1, C6.1, C7.1, F1.2, J6.1, R1.1, U1.2 (UVcc), U1.7 (VBUS), U1.14 (Vcc), U1.24 (AVcc), U1.34 (Vcc), U1.44 (AVcc)
/BUS+: P1.3 (D+), R3.2
/BUS-: P1.2 (D-), R2.1
/COL_1: KB1.16 (COL1), U1.37 (PF6/ADC6/TDO)
/COL_2: KB1.12 (COL2), U1.30 (PB6/PCINT6/OC1B/OC4B/ADC13)
/COL_3: KB1.8 (COL3), U1.26 (PD6/T1/~OC4D/ADC9)
/COL_4: KB1.9 (COL4), U1.27 (PD7/T0/OC4D/ADC10)
/COL_5: KB1.10 (COL5), U1.28 (PB4/ADC11/PCINT4)
/COL_6: KB1.11 (COL6), U1.29 (PB5/PCINT5/OC1A/~OC4B/ADC12)
/COL_7: KB1.7 (COL7), U1.25 (PD4/ICP1/ADC8)
/COL_8: KB1.6 (COL8), U1.22 (PD5/XCK1/~CTS)
/COL_9: KB1.2 (COL9), U1.18 (PD0/OC0B/SCL/INT0)
/COL_10: KB1.5 (COL10), U1.21 (PD3/TXD1/INT3)
/COL_11: KB1.4 (COL11), U1.20 (PD2/RXD1/AIN1/INT2)
/COL_12: KB1.3 (COL12), U1.19 (PD1/SDA/INT1)
/D+: J8.1, R3.1, U1.4 (D+)
/D-: J7.1, R2.2, U1.3 (D-)
/LED: D1.2 (A), U1.12 (PB7/PCINT7/OC0A/OC1C/~RTS)
/MISO: J3.1, U1.11 (PB3/PDO/PCINT3/MISO)
/MOSI: J4.1, U1.10 (PB2/PDI/PCINT2/MOSI)
/RESET: J1.1, R1.2, SW1.2, U1.13 (RESET)
/ROW_01: KB1.21 (ROW01), U1.40 (PF1/ADC1)
/ROW_02: KB1.17 (ROW02), U1.38 (PF5/ADC5/TMS)
/ROW_03: KB1.13 (ROW03), U1.31 (PC6/OC3A/~OC4A)
/ROW_04: KB1.14 (ROW04), U1.32 (PC7/ICP3/CLK0/OC4A)
/ROW_05: KB1.15 (ROW05), U1.36 (PF7/ADC7/TDI)
/ROW_06: KB1.18 (ROW06), U1.39 (PF4/ADC4/TCK)
/ROW_07: KB1.19 (ROW07), U1.1 (PE6/INT.6/AIN0)
/ROW_08: KB1.20 (ROW08), U1.41 (PF0/ADC0)
/SCK: J2.1, U1.9 (PB1/PCINT1/SCLK)
/TMP: U1.8 (PB0/SS/PCINT0)
/VARef: C8.1, U1.42 (AREF)
/VUCap: C9.1, U1.6 (UCap)
GND: C1.2, C2.2, C3.2, C4.2, C5.2, C6.2, C7.2, C8.2, C9.2, C10.2, C11.2, C12.1, J9.1, KB1.1 (NC), KB1.22 (NC), P1.5 (GND), R4.1, R5.1, SW1.1, U1.5 (UGND), U1.15 (GND), U1.23 (GND), U1.33 (PE2/~HWB), U1.35 (GND), U1.43 (GND), U1.45 (GNDT), Y1.2, Y1.4
GNDPWR: C12.2, P1.6 (shield), R4.2
unnamed: C10.1, U1.17 (XTAL1), Y1.3
unnamed: C11.1, U1.16 (XTAL2), Y1.1
unnamed: D1.1 (K), R5.2
VBUS: F1.1, J5.1, P1.1 (VCC)

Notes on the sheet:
ICSP

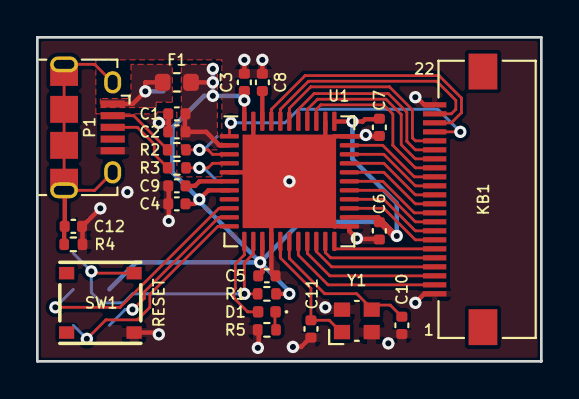
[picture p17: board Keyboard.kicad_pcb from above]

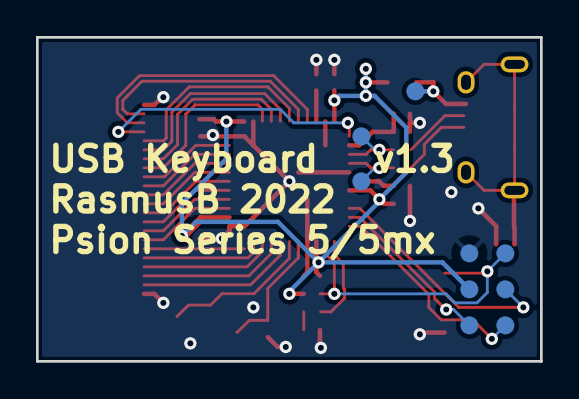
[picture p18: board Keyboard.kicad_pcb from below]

Board: 2 copper layers, 28.0 x 18.0 mm, 33 parts (9 on the bottom side), 38 nets.

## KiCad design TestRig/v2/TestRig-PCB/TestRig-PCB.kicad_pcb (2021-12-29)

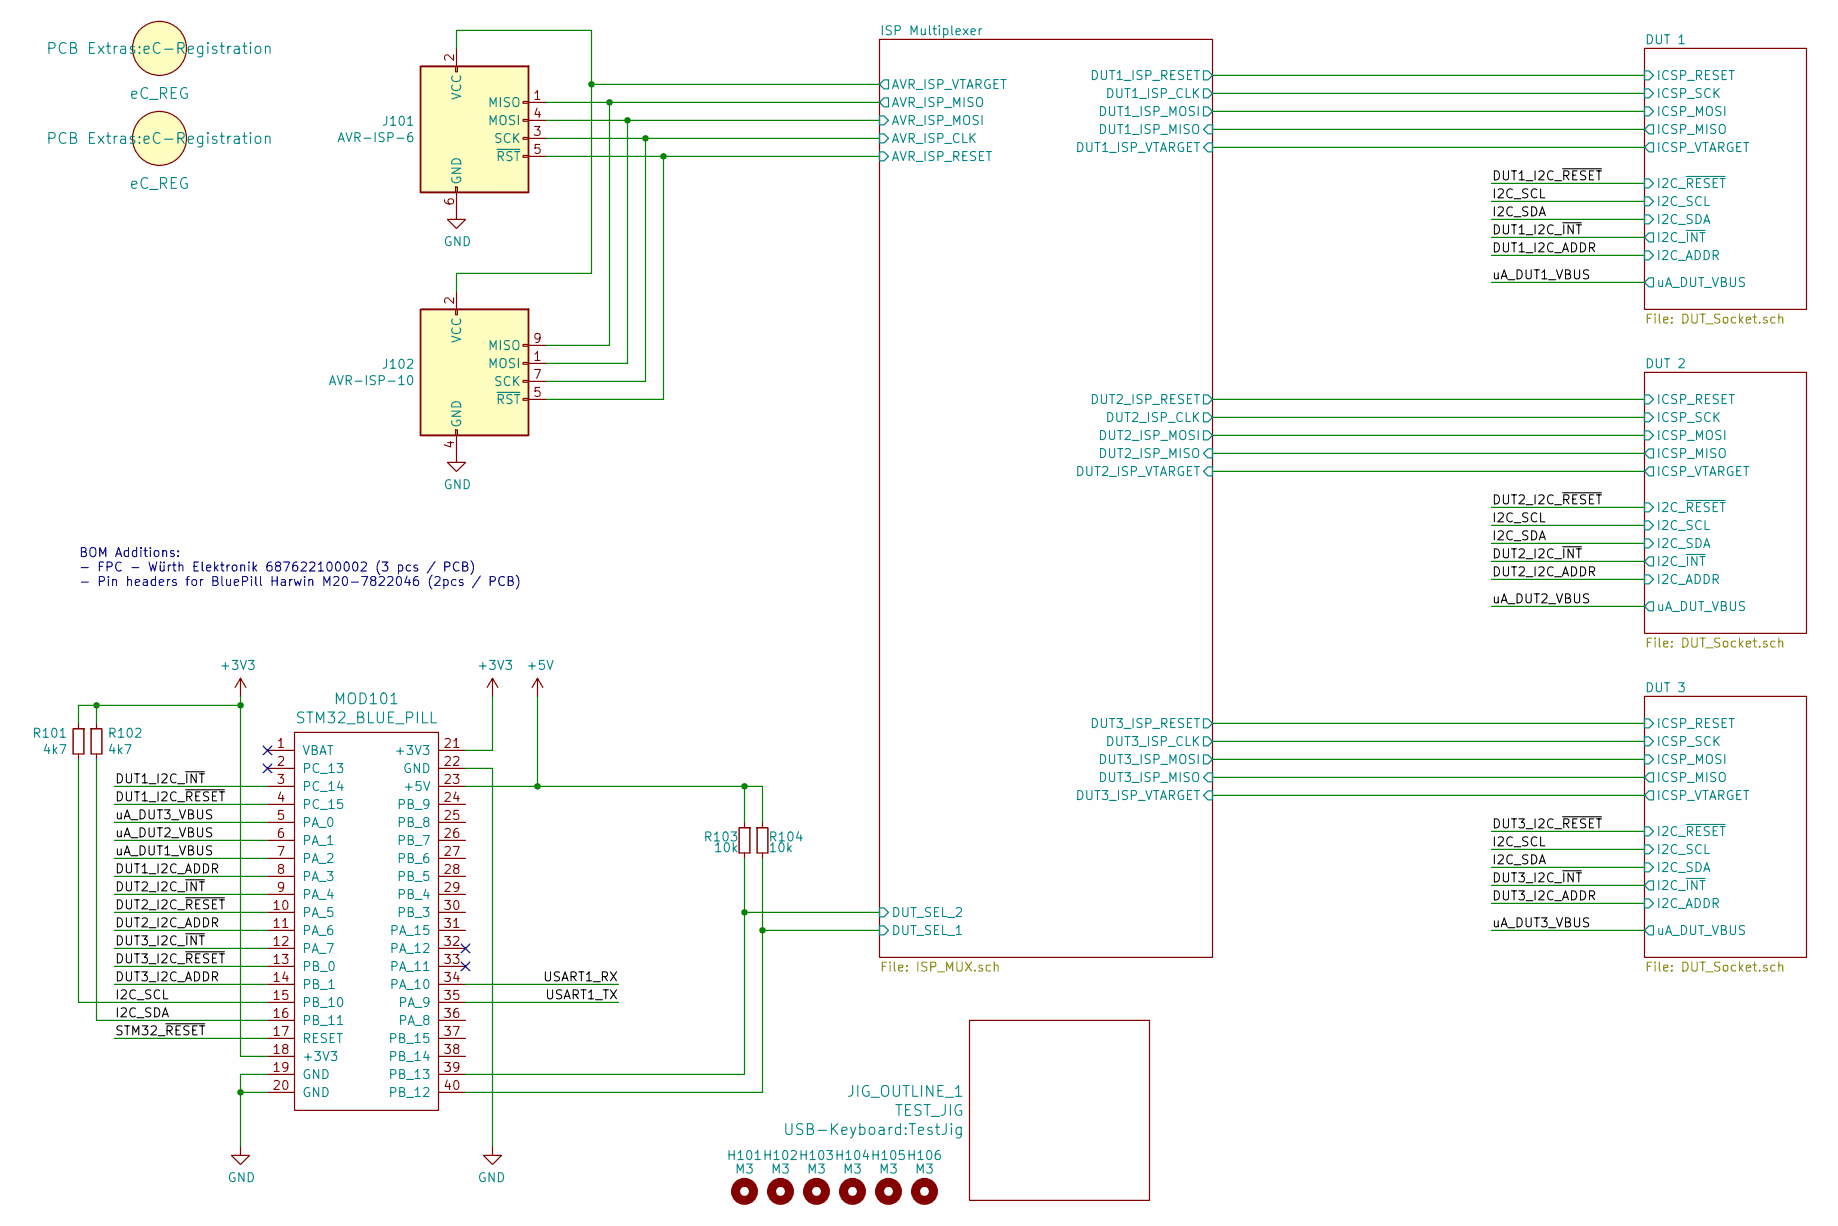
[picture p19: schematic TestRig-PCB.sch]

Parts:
H101, H102, H103, H104, H105, H106: M3; MountingHole_3.2mm_M3
J101: AVR-ISP-6; IDC-Header_2x03_P2.54mm_Vertical; MPN 87834-0619
J102: AVR-ISP-10; IDC-Header_2x05_P2.54mm_Vertical; MPN 70246-1001
JIG_OUTLINE_1: TEST_JIG; TestJig
MOD101: STM32_BLUE_PILL; STM32F103C8T6-ARM-BOARD
R101, R102: 4k7; R_0603_1608Metric; MPN CR0603-JW-472ELF
R103, R104: 10k; R_0603_1608Metric; MPN CR0603-JW-103ELF
REG101, REG102: eC_REG; eC-Registration

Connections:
+3V3: MOD101.18 (+3V3), MOD101.21 (+3V3), R101.1, R102.1; also elsewhere on the board
+5V: MOD101.23 (+5V), R103.1, R104.1; also elsewhere on the board
/DUT1_I2C_ADDR: MOD101.8 (PA_3); also elsewhere on the board
/DUT1_I2C_~INT: MOD101.3 (PC_14); also elsewhere on the board
/DUT1_I2C_~RESET: MOD101.4 (PC_15); also elsewhere on the board
/DUT2_I2C_ADDR: MOD101.11 (PA_6); also elsewhere on the board
/DUT2_I2C_~INT: MOD101.9 (PA_4); also elsewhere on the board
/DUT2_I2C_~RESET: MOD101.10 (PA_5); also elsewhere on the board
/DUT3_I2C_ADDR: MOD101.14 (PB_1); also elsewhere on the board
/DUT3_I2C_~INT: MOD101.12 (PA_7); also elsewhere on the board
/DUT3_I2C_~RESET: MOD101.13 (PB_0); also elsewhere on the board
/I2C_SCL: MOD101.15 (PB_10), R101.2; also elsewhere on the board
/I2C_SDA: MOD101.16 (PB_11), R102.2; also elsewhere on the board
/ISP Multiplexer/AVR_ISP_CLK: J101.3 (SCK), J102.7 (SCK); also elsewhere on the board
/ISP Multiplexer/AVR_ISP_MISO: J101.1 (MISO), J102.9 (MISO); also elsewhere on the board
/ISP Multiplexer/AVR_ISP_MOSI: J101.4 (MOSI), J102.1 (MOSI); also elsewhere on the board
/ISP Multiplexer/AVR_ISP_RESET: J101.5 (~RST), J102.5 (~RST); also elsewhere on the board
/ISP Multiplexer/AVR_ISP_VTARGET: J101.2 (VCC), J102.2 (VCC); also elsewhere on the board
/ISP Multiplexer/DUT_SEL_1: MOD101.40 (PB_12), R104.2; also elsewhere on the board
/ISP Multiplexer/DUT_SEL_2: MOD101.39 (PB_13), R103.2; also elsewhere on the board
/STM32_~RESET: MOD101.17 (RESET)
/USART1_RX: MOD101.34 (PA_10)
/USART1_TX: MOD101.35 (PA_9)
/uA_DUT1_VBUS: MOD101.7 (PA_2); also elsewhere on the board
/uA_DUT2_VBUS: MOD101.6 (PA_1); also elsewhere on the board
/uA_DUT3_VBUS: MOD101.5 (PA_0); also elsewhere on the board
GND: J101.6 (GND), J102.4 (GND), J102.6 (GND), J102.8 (GND), J102.10 (GND), MOD101.19 (GND), MOD101.20 (GND), MOD101.22 (GND); also elsewhere on the board

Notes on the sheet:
BOM Additions: - FPC - Würth Elektronik 687622100002 (3 pcs / PCB) - Pin headers for BluePill Harwin M20-7822046 (2pcs / PCB)

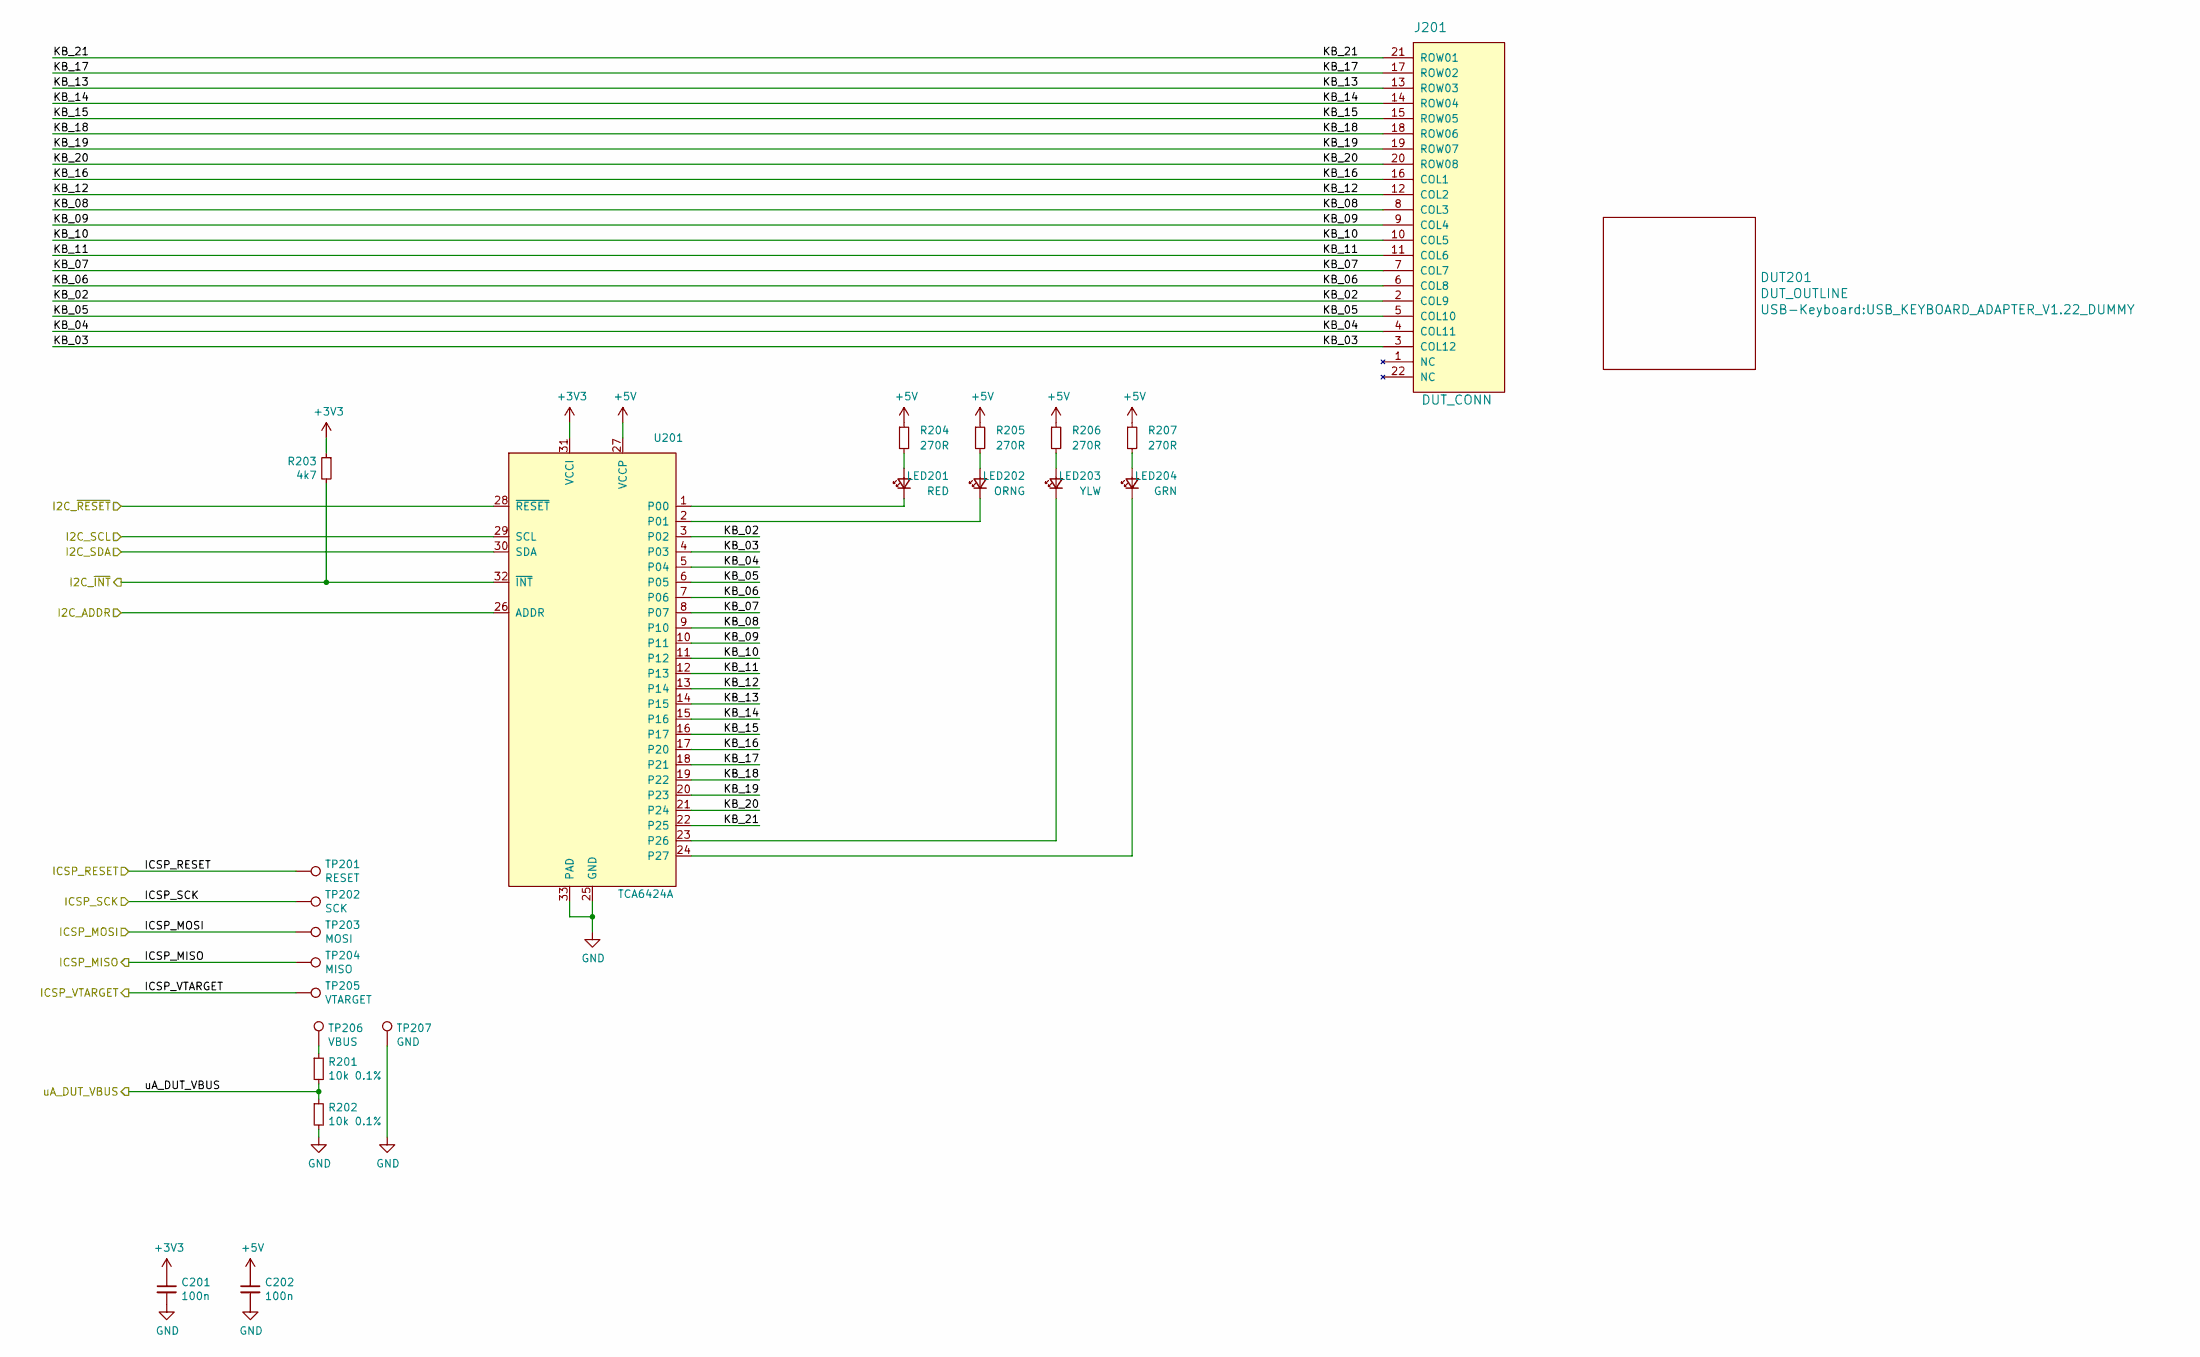
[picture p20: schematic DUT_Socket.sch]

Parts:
C201, C202: 100n; C_0603_1608Metric; MPN C0603C104Z3VACTU
DUT201: DUT_OUTLINE; USB_KEYBOARD_ADAPTER_V1.22_DUMMY
J201: DUT_CONN; Hirose_FH12-22S-0.5SH_1x22-1MP_P0.50mm_Horizontal; MPN FH12A-22S-0.5SH(55)
LED201: RED; LED_0603_1608Metric; MPN APT1608SRCPRV
LED202: ORNG; LED_0603_1608Metric; MPN APT1608SECK
LED203: YLW; LED_0603_1608Metric; MPN APT1608SYCK
LED204: GRN; LED_0603_1608Metric; MPN APT1608CGCK
R201, R202: 10k 0.1%; R_0603_1608Metric; MPN ERA-3AEB103V
R203: 4k7; R_0603_1608Metric; MPN CR0603-JW-472ELF
R204, R205, R206, R207: 270R; R_0603_1608Metric; MPN CRGCQ0603F270R
TP201: RESET; Pogo_P50_Bottom
TP202: SCK; Pogo_P50_Bottom
TP203: MOSI; Pogo_P50_Bottom
TP204: MISO; Pogo_P50_Bottom
TP205: VTARGET; Pogo_P50_Bottom
TP206: VBUS; Pogo_P50_Bottom
TP207: GND; Pogo_P50_Bottom
U201: TCA6424A; QFN-32-1EP_5x5mm_P0.5mm_EP3.1x3.1mm; MPN TCA6424ARGJR

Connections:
+3V3: C201.1, R203.1, U201.31 (VCCI); also elsewhere on the board
+5V: C202.1, R204.1, R205.1, R206.1, R207.1, U201.27 (VCCP); also elsewhere on the board
/DUT1_I2C_ADDR: U201.26 (ADDR); also elsewhere on the board
/DUT1_I2C_~INT: R203.2, U201.32 (~INT); also elsewhere on the board
/DUT1_I2C_~RESET: U201.28 (~RESET); also elsewhere on the board
/DUT 1/KB_02: J201.2 (COL9), U201.3 (P02)
/DUT 1/KB_03: J201.3 (COL12), U201.4 (P03)
/DUT 1/KB_04: J201.4 (COL11), U201.5 (P04)
/DUT 1/KB_05: J201.5 (COL10), U201.6 (P05)
/DUT 1/KB_06: J201.6 (COL8), U201.7 (P06)
/DUT 1/KB_07: J201.7 (COL7), U201.8 (P07)
/DUT 1/KB_08: J201.8 (COL3), U201.9 (P10)
/DUT 1/KB_09: J201.9 (COL4), U201.10 (P11)
/DUT 1/KB_10: J201.10 (COL5), U201.11 (P12)
/DUT 1/KB_11: J201.11 (COL6), U201.12 (P13)
/DUT 1/KB_12: J201.12 (COL2), U201.13 (P14)
/DUT 1/KB_13: J201.13 (ROW03), U201.14 (P15)
/DUT 1/KB_14: J201.14 (ROW04), U201.15 (P16)
/DUT 1/KB_15: J201.15 (ROW05), U201.16 (P17)
/DUT 1/KB_16: J201.16 (COL1), U201.17 (P20)
/DUT 1/KB_17: J201.17 (ROW02), U201.18 (P21)
/DUT 1/KB_18: J201.18 (ROW06), U201.19 (P22)
/DUT 1/KB_19: J201.19 (ROW07), U201.20 (P23)
/DUT 1/KB_20: J201.20 (ROW08), U201.21 (P24)
/DUT 1/KB_21: J201.21 (ROW01), U201.22 (P25)
/I2C_SCL: U201.29 (SCL); also elsewhere on the board
/I2C_SDA: U201.30 (SDA); also elsewhere on the board
/ISP Multiplexer/DUT1_ISP_CLK: TP202.1; also elsewhere on the board
/ISP Multiplexer/DUT1_ISP_MISO: TP204.1; also elsewhere on the board
/ISP Multiplexer/DUT1_ISP_MOSI: TP203.1; also elsewhere on the board
/ISP Multiplexer/DUT1_ISP_RESET: TP201.1; also elsewhere on the board
/ISP Multiplexer/DUT1_ISP_VTARGET: TP205.1; also elsewhere on the board
/uA_DUT1_VBUS: R201.2, R202.1; also elsewhere on the board
GND: C201.2, C202.2, R202.2, TP207.1, U201.25 (GND), U201.33 (PAD); also elsewhere on the board
unnamed: LED201.1 (K), U201.1 (P00)
unnamed: LED201.2 (A), R204.2
unnamed: LED202.1 (K), U201.2 (P01)
unnamed: LED202.2 (A), R205.2
unnamed: LED203.1 (K), U201.23 (P26)
unnamed: LED203.2 (A), R206.2
unnamed: LED204.1 (K), U201.24 (P27)
unnamed: LED204.2 (A), R207.2
unnamed: R201.1, TP206.1

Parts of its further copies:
C401, C402, C501, C502: 100n; C_0603_1608Metric; MPN C0603C104Z3VACTU
DUT401, DUT501: DUT_OUTLINE; USB_KEYBOARD_ADAPTER_V1.22_DUMMY
J401, J501: DUT_CONN; Hirose_FH12-22S-0.5SH_1x22-1MP_P0.50mm_Horizontal; MPN FH12A-22S-0.5SH(55)
LED401, LED501: RED; LED_0603_1608Metric; MPN APT1608SRCPRV
LED402, LED502: ORNG; LED_0603_1608Metric; MPN APT1608SECK
LED403, LED503: YLW; LED_0603_1608Metric; MPN APT1608SYCK
LED404, LED504: GRN; LED_0603_1608Metric; MPN APT1608CGCK
R403, R503: 4k7; R_0603_1608Metric; MPN CR0603-JW-472ELF
R404, R405, R406, R407, R504, R505, R506, R507: 270R; R_0603_1608Metric; MPN CRGCQ0603F270R
TP401, TP501: RESET; Pogo_P50_Bottom
TP402, TP502: SCK; Pogo_P50_Bottom
TP403, TP503: MOSI; Pogo_P50_Bottom
TP404, TP504: MISO; Pogo_P50_Bottom
TP405, TP505: VTARGET; Pogo_P50_Bottom
TP406, TP506: VBUS; Pogo_P50_Bottom
TP407, TP507: GND; Pogo_P50_Bottom
U401, U501: TCA6424A; QFN-32-1EP_5x5mm_P0.5mm_EP3.1x3.1mm; MPN TCA6424ARGJR

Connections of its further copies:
+3V3: C401.1, C501.1, R403.1, R503.1, U401.31 (VCCI), U501.31 (VCCI); also elsewhere on the board
+5V: C402.1, C502.1, R404.1, R405.1, R406.1, R407.1, R504.1, R505.1, R506.1, R507.1, U401.27 (VCCP), U501.27 (VCCP); also elsewhere on the board
/DUT2_I2C_ADDR: U401.26 (ADDR); also elsewhere on the board
/DUT2_I2C_~INT: R403.2, U401.32 (~INT); also elsewhere on the board
/DUT2_I2C_~RESET: U401.28 (~RESET); also elsewhere on the board
/DUT3_I2C_ADDR: U501.26 (ADDR); also elsewhere on the board
/DUT3_I2C_~INT: R503.2, U501.32 (~INT); also elsewhere on the board
/DUT3_I2C_~RESET: U501.28 (~RESET); also elsewhere on the board
/DUT 2/KB_02: J401.2 (COL9), U401.3 (P02)
/DUT 2/KB_03: J401.3 (COL12), U401.4 (P03)
/DUT 2/KB_04: J401.4 (COL11), U401.5 (P04)
/DUT 2/KB_05: J401.5 (COL10), U401.6 (P05)
/DUT 2/KB_06: J401.6 (COL8), U401.7 (P06)
/DUT 2/KB_07: J401.7 (COL7), U401.8 (P07)
/DUT 2/KB_08: J401.8 (COL3), U401.9 (P10)
/DUT 2/KB_09: J401.9 (COL4), U401.10 (P11)
/DUT 2/KB_10: J401.10 (COL5), U401.11 (P12)
/DUT 2/KB_11: J401.11 (COL6), U401.12 (P13)
/DUT 2/KB_12: J401.12 (COL2), U401.13 (P14)
/DUT 2/KB_13: J401.13 (ROW03), U401.14 (P15)
/DUT 2/KB_14: J401.14 (ROW04), U401.15 (P16)
/DUT 2/KB_15: J401.15 (ROW05), U401.16 (P17)
/DUT 2/KB_16: J401.16 (COL1), U401.17 (P20)
/DUT 2/KB_17: J401.17 (ROW02), U401.18 (P21)
/DUT 2/KB_18: J401.18 (ROW06), U401.19 (P22)
/DUT 2/KB_19: J401.19 (ROW07), U401.20 (P23)
/DUT 2/KB_20: J401.20 (ROW08), U401.21 (P24)
/DUT 2/KB_21: J401.21 (ROW01), U401.22 (P25)
/DUT 3/KB_02: J501.2 (COL9), U501.3 (P02)
/DUT 3/KB_03: J501.3 (COL12), U501.4 (P03)
/DUT 3/KB_04: J501.4 (COL11), U501.5 (P04)
/DUT 3/KB_05: J501.5 (COL10), U501.6 (P05)
/DUT 3/KB_06: J501.6 (COL8), U501.7 (P06)
/DUT 3/KB_07: J501.7 (COL7), U501.8 (P07)
/DUT 3/KB_08: J501.8 (COL3), U501.9 (P10)
/DUT 3/KB_09: J501.9 (COL4), U501.10 (P11)
/DUT 3/KB_10: J501.10 (COL5), U501.11 (P12)
/DUT 3/KB_11: J501.11 (COL6), U501.12 (P13)
/DUT 3/KB_12: J501.12 (COL2), U501.13 (P14)
/DUT 3/KB_13: J501.13 (ROW03), U501.14 (P15)
/DUT 3/KB_14: J501.14 (ROW04), U501.15 (P16)
/DUT 3/KB_15: J501.15 (ROW05), U501.16 (P17)
/DUT 3/KB_16: J501.16 (COL1), U501.17 (P20)
/DUT 3/KB_17: J501.17 (ROW02), U501.18 (P21)
/DUT 3/KB_18: J501.18 (ROW06), U501.19 (P22)
/DUT 3/KB_19: J501.19 (ROW07), U501.20 (P23)
/DUT 3/KB_20: J501.20 (ROW08), U501.21 (P24)
/DUT 3/KB_21: J501.21 (ROW01), U501.22 (P25)
/I2C_SCL: U401.29 (SCL), U501.29 (SCL); also elsewhere on the board
/I2C_SDA: U401.30 (SDA), U501.30 (SDA); also elsewhere on the board
/ISP Multiplexer/DUT2_ISP_CLK: TP402.1; also elsewhere on the board
/ISP Multiplexer/DUT2_ISP_MISO: TP404.1; also elsewhere on the board
/ISP Multiplexer/DUT2_ISP_MOSI: TP403.1; also elsewhere on the board
/ISP Multiplexer/DUT2_ISP_RESET: TP401.1; also elsewhere on the board
/ISP Multiplexer/DUT2_ISP_VTARGET: TP405.1; also elsewhere on the board
/ISP Multiplexer/DUT3_ISP_CLK: TP502.1; also elsewhere on the board
/ISP Multiplexer/DUT3_ISP_MISO: TP504.1; also elsewhere on the board
/ISP Multiplexer/DUT3_ISP_MOSI: TP503.1; also elsewhere on the board
/ISP Multiplexer/DUT3_ISP_RESET: TP501.1; also elsewhere on the board
/ISP Multiplexer/DUT3_ISP_VTARGET: TP505.1; also elsewhere on the board
GND: C401.2, C402.2, C501.2, C502.2, TP407.1, TP507.1, U401.25 (GND), U401.33 (PAD), U501.25 (GND), U501.33 (PAD); also elsewhere on the board
unnamed: LED401.1 (K), U401.1 (P00)
unnamed: LED401.2 (A), R404.2
unnamed: LED402.1 (K), U401.2 (P01)
unnamed: LED402.2 (A), R405.2
unnamed: LED403.1 (K), U401.23 (P26)
unnamed: LED403.2 (A), R406.2
unnamed: LED404.1 (K), U401.24 (P27)
unnamed: LED404.2 (A), R407.2
unnamed: LED501.1 (K), U501.1 (P00)
unnamed: LED501.2 (A), R504.2
unnamed: LED502.1 (K), U501.2 (P01)
unnamed: LED502.2 (A), R505.2
unnamed: LED503.1 (K), U501.23 (P26)
unnamed: LED503.2 (A), R506.2
unnamed: LED504.1 (K), U501.24 (P27)
unnamed: LED504.2 (A), R507.2
unnamed 149: TP406.1; also elsewhere on the board
unnamed 150: TP506.1; also elsewhere on the board

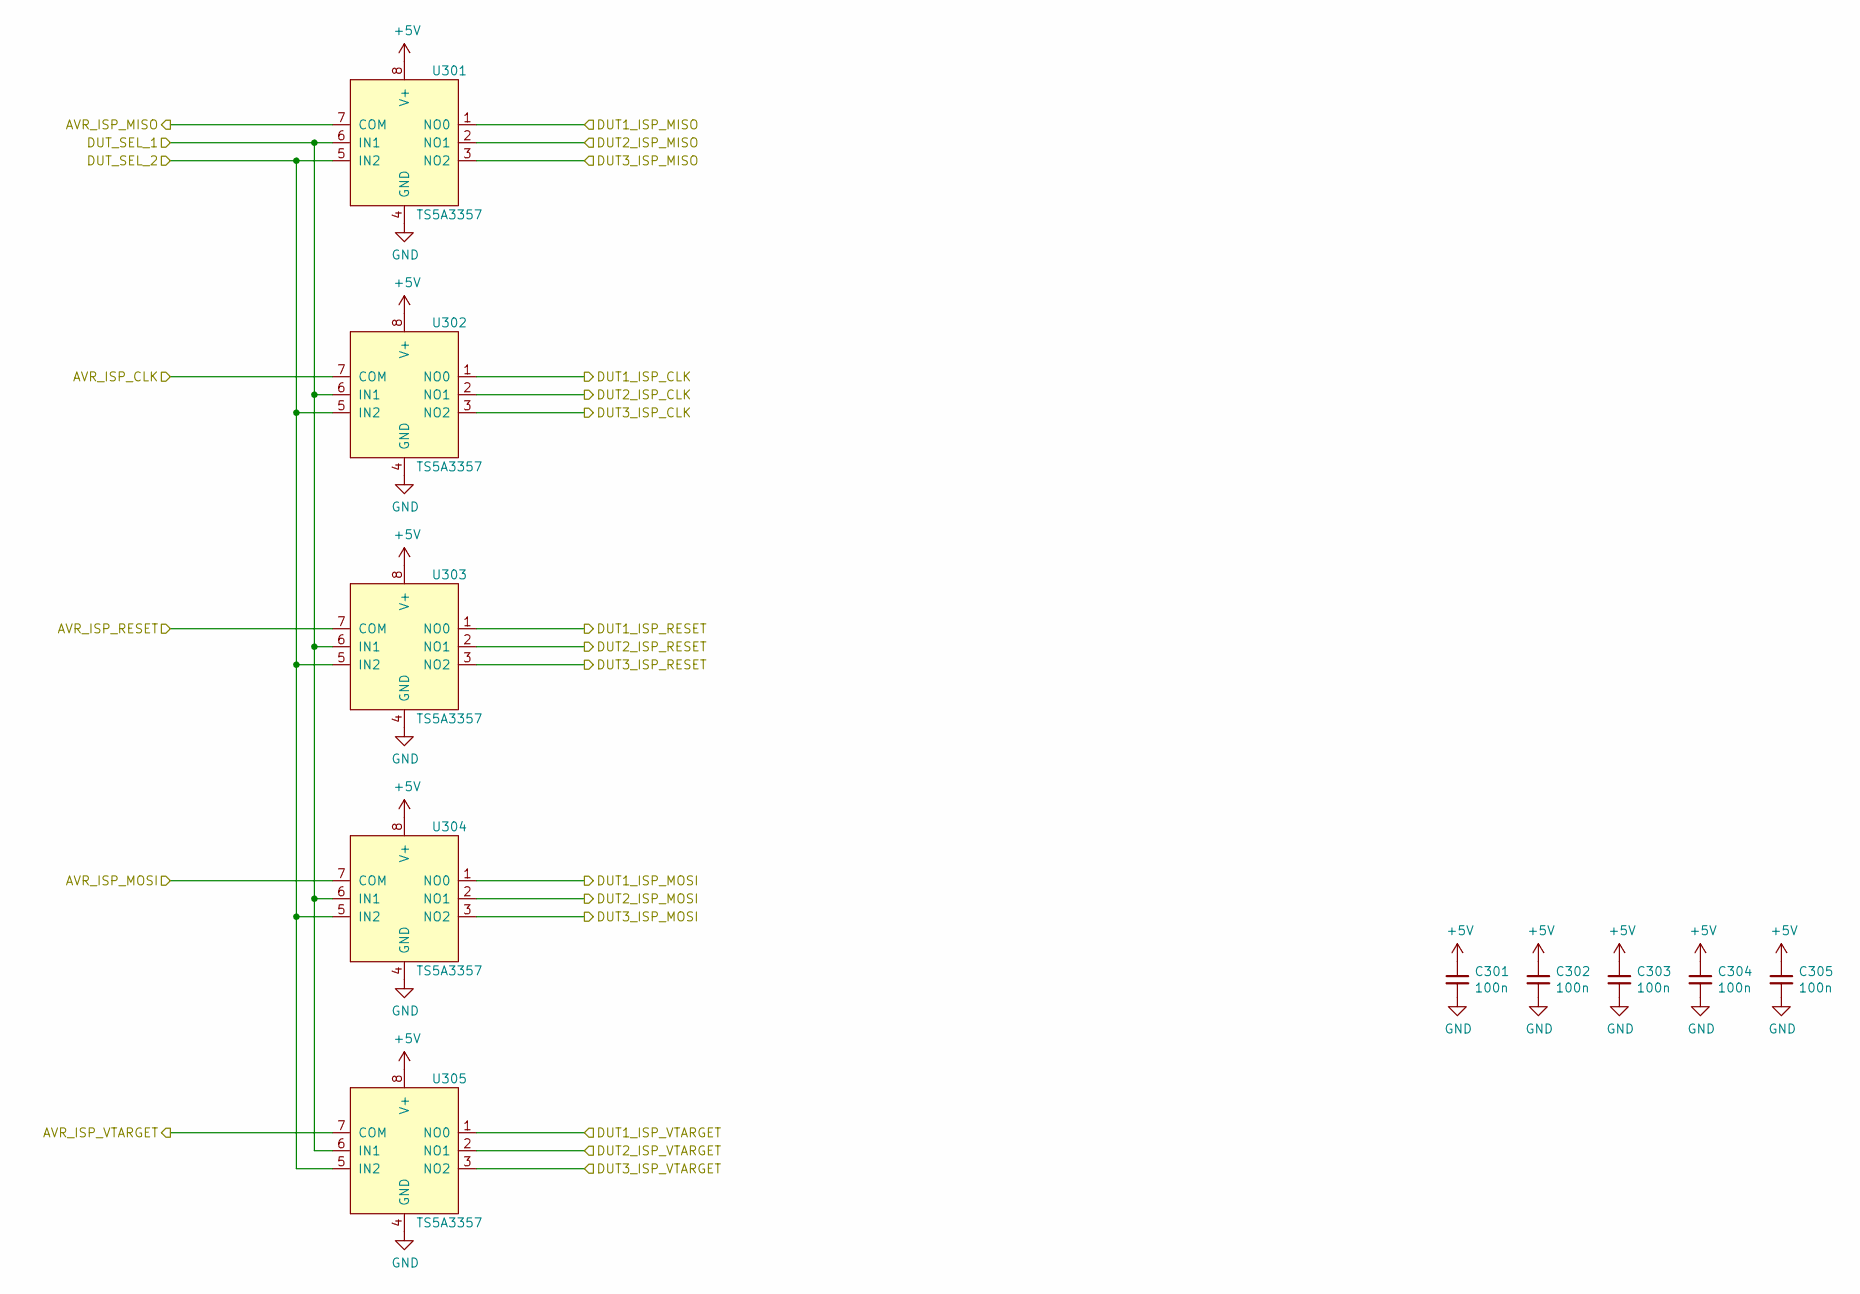
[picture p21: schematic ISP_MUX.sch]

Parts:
C301, C302, C303, C304, C305: 100n; C_0603_1608Metric; MPN C0603C104Z3VACTU
U301, U302, U303, U304, U305: TS5A3357; VSSOP-8_2.3x2mm_P0.5mm; MPN TS5A3357DCUR

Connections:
+5V: C301.1, C302.1, C303.1, C304.1, C305.1, U301.8 (V+), U302.8 (V+), U303.8 (V+), U304.8 (V+), U305.8 (V+); also elsewhere on the board
/ISP Multiplexer/AVR_ISP_CLK: U302.7 (COM); also elsewhere on the board
/ISP Multiplexer/AVR_ISP_MISO: U301.7 (COM); also elsewhere on the board
/ISP Multiplexer/AVR_ISP_MOSI: U304.7 (COM); also elsewhere on the board
/ISP Multiplexer/AVR_ISP_RESET: U303.7 (COM); also elsewhere on the board
/ISP Multiplexer/AVR_ISP_VTARGET: U305.7 (COM); also elsewhere on the board
/ISP Multiplexer/DUT1_ISP_CLK: U302.1 (NO0); also elsewhere on the board
/ISP Multiplexer/DUT1_ISP_MISO: U301.1 (NO0); also elsewhere on the board
/ISP Multiplexer/DUT1_ISP_MOSI: U304.1 (NO0); also elsewhere on the board
/ISP Multiplexer/DUT1_ISP_RESET: U303.1 (NO0); also elsewhere on the board
/ISP Multiplexer/DUT1_ISP_VTARGET: U305.1 (NO0); also elsewhere on the board
/ISP Multiplexer/DUT2_ISP_CLK: U302.2 (NO1); also elsewhere on the board
/ISP Multiplexer/DUT2_ISP_MISO: U301.2 (NO1); also elsewhere on the board
/ISP Multiplexer/DUT2_ISP_MOSI: U304.2 (NO1); also elsewhere on the board
/ISP Multiplexer/DUT2_ISP_RESET: U303.2 (NO1); also elsewhere on the board
/ISP Multiplexer/DUT2_ISP_VTARGET: U305.2 (NO1); also elsewhere on the board
/ISP Multiplexer/DUT3_ISP_CLK: U302.3 (NO2); also elsewhere on the board
/ISP Multiplexer/DUT3_ISP_MISO: U301.3 (NO2); also elsewhere on the board
/ISP Multiplexer/DUT3_ISP_MOSI: U304.3 (NO2); also elsewhere on the board
/ISP Multiplexer/DUT3_ISP_RESET: U303.3 (NO2); also elsewhere on the board
/ISP Multiplexer/DUT3_ISP_VTARGET: U305.3 (NO2); also elsewhere on the board
/ISP Multiplexer/DUT_SEL_1: U301.6 (IN1), U302.6 (IN1), U303.6 (IN1), U304.6 (IN1), U305.6 (IN1); also elsewhere on the board
/ISP Multiplexer/DUT_SEL_2: U301.5 (IN2), U302.5 (IN2), U303.5 (IN2), U304.5 (IN2), U305.5 (IN2); also elsewhere on the board
GND: C301.2, C302.2, C303.2, C304.2, C305.2, U301.4 (GND), U302.4 (GND), U303.4 (GND), U304.4 (GND), U305.4 (GND); also elsewhere on the board

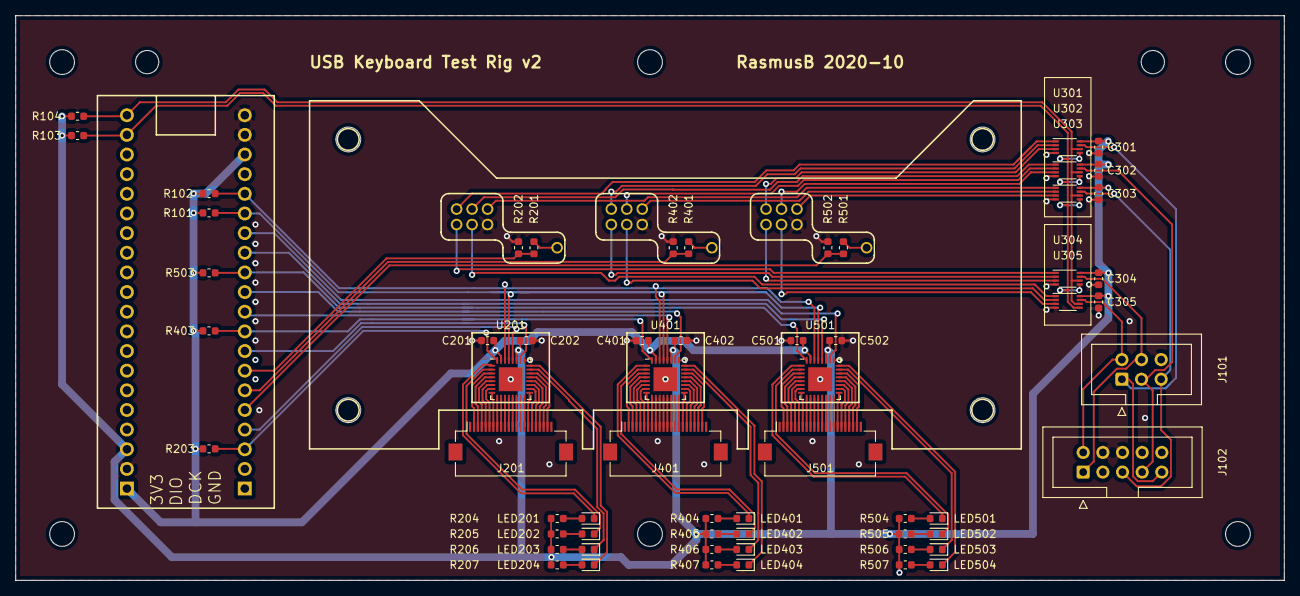
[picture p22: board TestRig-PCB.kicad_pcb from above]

Board: 2 copper layers, 164.0 x 73.0 mm, 95 parts (0 on the bottom side), 126 nets.

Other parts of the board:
R401, R402, R501, R502: 10k 1%; R_0603_1608Metric

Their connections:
/uA_DUT2_VBUS: R401.2, R402.1; also elsewhere on the board
/uA_DUT3_VBUS: R501.2, R502.1; also elsewhere on the board
GND: R402.2, R502.2; also elsewhere on the board
unnamed 149: R401.1; also elsewhere on the board
unnamed 150: R501.1; also elsewhere on the board

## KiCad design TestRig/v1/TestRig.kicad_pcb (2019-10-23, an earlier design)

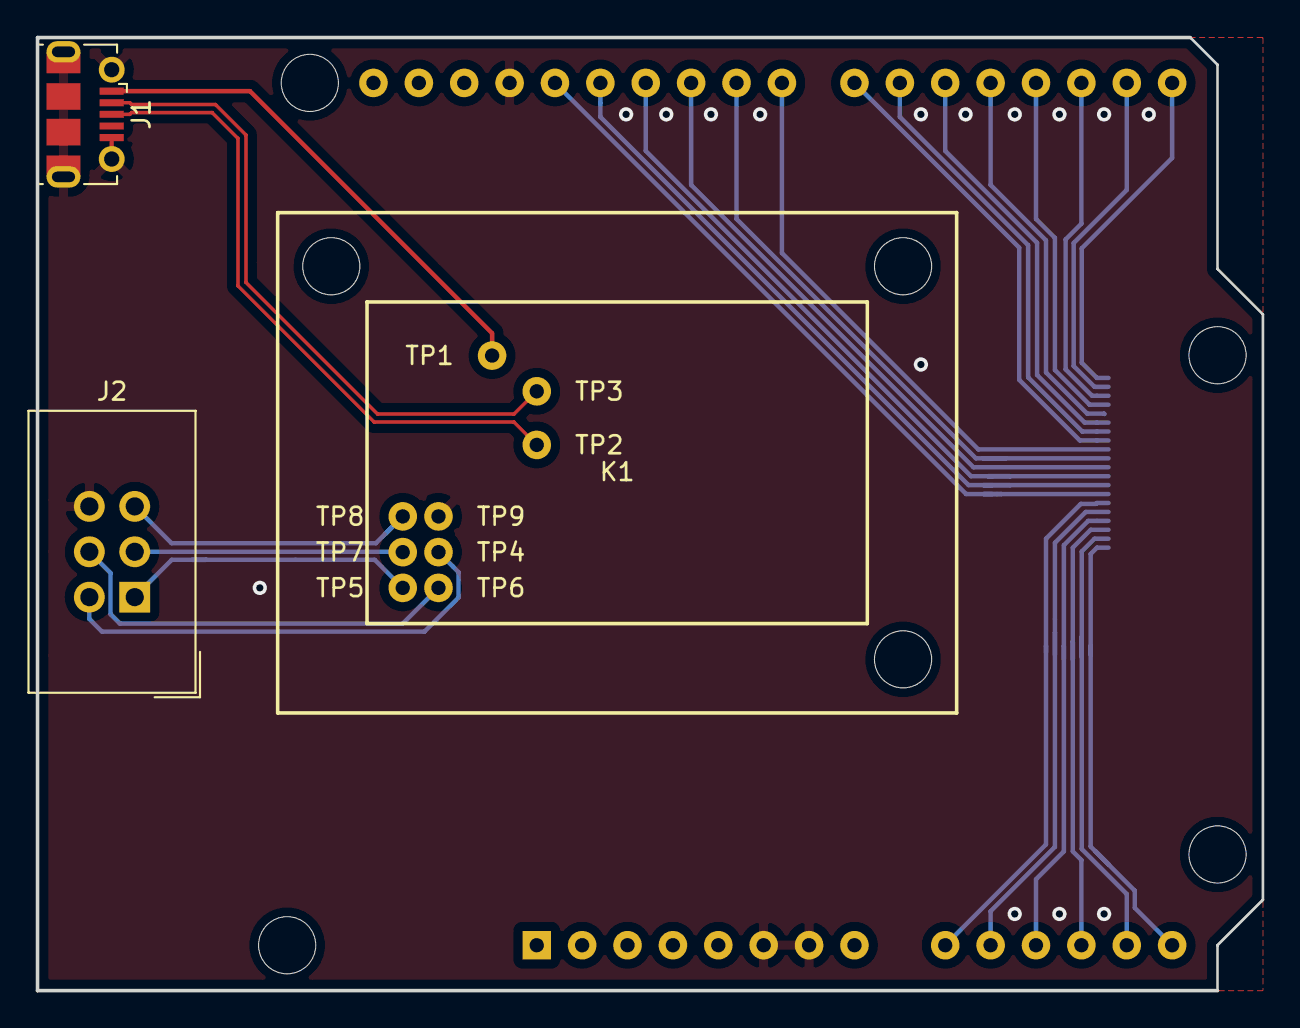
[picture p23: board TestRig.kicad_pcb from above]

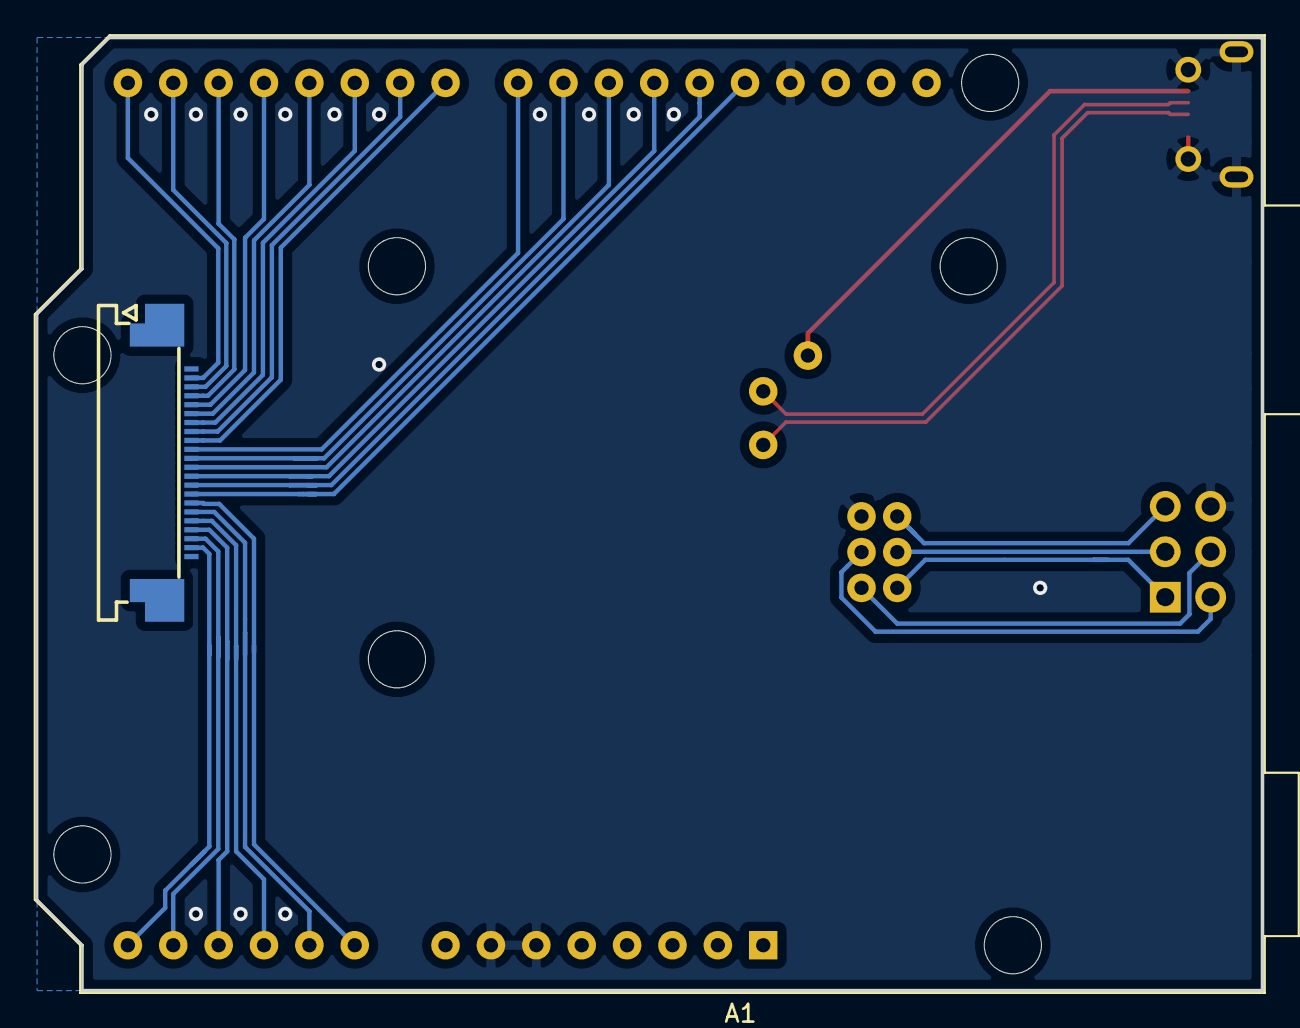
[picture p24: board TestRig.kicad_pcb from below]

Board: 2 copper layers, 68.6 x 53.3 mm, 18 parts (2 on the bottom side), 29 nets.

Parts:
A1: Arduino_UNO_R3; Arduino_UNO_R3_WithMountingHoles
J1: USB_B_Micro; USB_Micro-B_Molex-105017-0001
J2: AVR-ISP-6; IDC-Header_2x03_P2.54mm_Vertical
J3: To DUT; FPC_0.5mm_22p-MOLEX_52437
K1: PCB Jig 3D model; PCB_JIG
K2: 3D Model Dummy; USB_KEYBOARD_ADAPTER_V1.22_DUMMY
MH1, MH2, MH3: MountingHole; MountingHole_3.2mm_M3
TP1: VBUS; Mill-Max_7911-0-15-20-86-14-11-0
TP2: USB_D+; Mill-Max_7911-0-15-20-86-14-11-0
TP3: USB_D-; Mill-Max_7911-0-15-20-86-14-11-0
TP4: VCC; Mill-Max_7911-0-15-20-86-14-11-0
TP5: MISO; Mill-Max_7911-0-15-20-86-14-11-0
TP6: MOSI; Mill-Max_7911-0-15-20-86-14-11-0
TP7: SCK; Mill-Max_7911-0-15-20-86-14-11-0
TP8: ~RST; Mill-Max_7911-0-15-20-86-14-11-0
TP9: GND; Mill-Max_7911-0-15-20-86-14-11-0

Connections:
/D+: J1.3, TP2.1
/D-: J1.2, TP3.1
/FPC1: A1.15, J3.2
/FPC2: A1.16, J3.3
/FPC3: A1.17, J3.4
/FPC4: A1.18, J3.5
/FPC5: A1.19, J3.6
/FPC6: A1.20, J3.7
/FPC7: A1.21, J3.8
/FPC8: A1.22, J3.9
/FPC9: A1.23, J3.10
/FPC10: A1.24, J3.11
/FPC11: A1.25, J3.12
/FPC12: A1.26, J3.13
/FPC13: A1.27, J3.14
/FPC14: A1.28, J3.15
/FPC15: A1.9, J3.16
/FPC16: A1.10, J3.17
/FPC17: A1.11, J3.18
/FPC18: A1.12, J3.19
/FPC19: A1.13, J3.20
/FPC20: A1.14, J3.21
/MISO: J2.1, TP5.1
/MOSI: J2.4, TP6.1
/SCK: J2.3, TP7.1
/~RST: J2.5, TP8.1
GND: A1.6, A1.7, A1.29, J1.5, J1.6, J2.6, TP9.1
VBUS: J1.1, TP1.1
VCC: J2.2, TP4.1

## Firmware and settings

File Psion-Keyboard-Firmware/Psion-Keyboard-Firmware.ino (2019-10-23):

/*
  Psion-Keyboard-Firmware

  See https://github.com/RasmusB/USB-Keyboard-Adapter

  This is firmware for turning a Psion Series 5/5mx or Ericsson MC 128
  keyboard into a USB keyboard. The firmare is intended to run on an
  ATmega32U4.

*/

#include "board.h"
#include "Keyboard.h"
#include "PsionKeymapUSB.h"

#define SERIAL_ENABLED true
#define DEBUG_ENABLED false
#define KEYBOARD_ENABLED true

// Max number of scans/second
#define MAX_SCAN_RATE 1000

int keypressArrayCurrent [NROWS] [NCOLS];
int keypressArrayPrevious [NROWS] [NCOLS];

unsigned long previousTime;
unsigned int minDelay;

void setup() {

  previousTime = 0;
  minDelay = 1000 / MAX_SCAN_RATE;

  if (SERIAL_ENABLED) {
    Serial.begin(9600);
    Serial.println("Hello!");
  }

  if (KEYBOARD_ENABLED) Keyboard.begin();

  pinMode(LED_BUILTIN, OUTPUT);

  // Scanlines in high-Z (inactive) mode
  // Pin state should be initialized to LOW
  for (int i = 0; i < NROWS; i++) {
    pinMode(Rows[i], INPUT);
  }

  // Columns as inputs
  // Internal pull-up enabled
  for (int i = 0; i < NCOLS; i++) {
    pinMode(Cols[i], INPUT);
  }
}

void loop() {

  if ( (millis() - previousTime) >= minDelay ) {

    // Scan the keyboard matrix
    int nKeysPressed = scanKeyboard(keypressArrayCurrent);

    //digitalWrite(LED_BUILTIN, keypressArrayCurrent[7][7]);

    if (nKeysPressed == 0) {
      digitalWrite(LED_BUILTIN, LOW);
    } else {
      digitalWrite(LED_BUILTIN, HIGH);
    }

    if ( SERIAL_ENABLED ) {
      Serial.print("n pressed: ");
      Serial.println(nKeysPressed);
    }

    // Send the keypresses over USB
    if (KEYBOARD_ENABLED) {
      sendKeys(keypressArrayCurrent, keypressArrayPrevious);
    }

    // Remember which keys were pressed so we can release them later
    memcpy(keypressArrayPrevious, keypressArrayCurrent, sizeof(keypressArrayCurrent));

    previousTime = millis();
  }
}

int scanKeyboard ( int keyArray [] [NCOLS] ) {

  int nKeysPressed = 0;

  for (int row = 0; row < NROWS; row++) {
    if (SERIAL_ENABLED && DEBUG_ENABLED) {
      Serial.print("Scanning row ");
      Serial.println(row);
    }

    // Select a pin to sink current
    pinMode(Rows[row], OUTPUT);
    digitalWrite(Rows[row], LOW);

    for (int col = 0; col < NCOLS; col++) {
      pinMode(Cols[col], INPUT_PULLUP);
      if (SERIAL_ENABLED && DEBUG_ENABLED) {
        Serial.print("Scanning col. ");
        Serial.println(col);
      }

      // Only scan mapped buttons
      if (keyScancode[row][col] != 0) {

        // =1 for every button NOT pressed (pull-ups enabled)
        // =0 for every button PRESSED (signal shorted to row pin)
        // This value is inverted when saved

        if ( digitalRead(Cols[col]) != HIGH ) {
          keyArray [row] [col] = 1;
          nKeysPressed++;

        } else {
          keyArray [row] [col] = 0;
        }
      }
      
      // Disable pull-up
      pinMode(Cols[col], INPUT);
      
    }

    // Return pin to high-Z (inactive) mode

    pinMode(Rows[row], INPUT);

  }

  return nKeysPressed;
}

void sendKeys ( int pressedArray [] [NCOLS], int previousArray [] [NCOLS] ) {

  for ( int row = 0; row < NROWS; row++ ) {
    for ( int col = 0; col < NCOLS; col++ ) {

      // Only scan mapped buttons
      if (keyScancode[row][col] != 0) {

        // If a new button is pressed
        if ( pressedArray[row][col] > previousArray[row][col] ) {

          if (SERIAL_ENABLED) {
            Serial.print("0x");
            Serial.print(keyScancode[row][col], HEX);
            Serial.println(" pressed");
          };

          // Ugly hack to fix the Delete Key under Windows
          // Is the backspace key pressed?
          if ( row == 2 && col == 4) {

            if (SERIAL_ENABLED) {
              Serial.println("BACKSPACE PRESSED");
              Serial.print("LSHIFT is ");
              Serial.println(pressedArray[0][6]);
              Serial.print("RSHIFT is ");
              Serial.println(pressedArray[7][7]);
            }

            // Is any of the shift keys pressed?
            if ( pressedArray[0][6] > 0 || pressedArray[7][7] > 0 ) {

              if (SERIAL_ENABLED) Serial.println("Trying to send DELETE");

              // Shift is pressed, send DELETE
              Keyboard.press(KEY_DELETE);

            } else {
              // No Shift key pressed, send BACKSPACE
              Keyboard.press(KEY_BACKSPACE);
            }

          } else if ( (row == 0 && col == 6) || (row == 7 && col == 7) ) {
            // Special handling of the SHIFT keys
            // Since we need to press SHIFT to send the KEY_DELETE, we need
            // to make sure that we don't send the shift key as well unless
            // BOTH shift keys are pressed...

            if (SERIAL_ENABLED) Serial.println("Handling SHIFT keys...");

            if (pressedArray[2][4] > 0) {
              // BACKSPACE/DELETE key is pressed
              if ( (pressedArray[0][6] > 0) && (pressedArray[7][7] > 0) ) {
                // Both shift keys are pressed, send the SHIFT keys
                if (SERIAL_ENABLED) Serial.println("Both SHIFT pressed");
                Keyboard.press(keyScancode[row][col]);
              } // If only one was pressed, we don't want to send SHIFT.
            } else {
              // Backspace / delete is not pressed
              // Send the shift keys as usual
              Keyboard.press(keyScancode[row][col]);
            }
          } else {
            // "Normal" keypress, just send as is
            Keyboard.press(keyScancode[row][col]);
          }


          // This handles the release of keys
        } else if ( pressedArray[row][col] < previousArray[row][col] ) {

          if (SERIAL_ENABLED) {
            Serial.print("0x");
            Serial.print(keyScancode[row][col], HEX);
            Serial.println(" released");
          };

          // Make sure we release either BACKSPACE or DELETE; whatever was pressed
          if ( row == 2 && col == 4) {
            Keyboard.release(KEY_DELETE);
            Keyboard.release(KEY_BACKSPACE);
          } else {
            Keyboard.release(keyScancode[row][col]);
          }

        }
      }
    }
  }

}

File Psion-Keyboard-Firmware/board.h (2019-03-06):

/*
 board.h
 
 This is how the pins are connected to the keyboard
 
 */

// This disables the RX and TX LEDs that are not on this PCB
#undef TXLED0
#undef RXLED0
#undef TXLED1
#undef RXLED1
#undef TX_RX_LED_INIT

#undef LED_BUILTIN_RX
#undef LED_BUILTIN_TX

#define TXLED0 0
#define RXLED0 0 
#define TXLED1 0
#define RXLED1 0
#define TX_RX_LED_INIT 0


#define LED_BUILTIN_RX 0
#define LED_BUILTIN_TX 0


// Standard LED is moved to pin 11
#undef LED_BUILTIN
#define LED_BUILTIN 11
 
// See the keyboard schematic for row/col mapping
#define NROWS 8
#define NCOLS 12

#define ROW_01  22
#define ROW_02  20
#define ROW_03  5
#define ROW_04  13
#define ROW_05  18
#define ROW_06  21
#define ROW_07  7
#define ROW_08  23

#define COL_1   19
#define COL_2   10
#define COL_3   9
#define COL_4   8
#define COL_5   6
#define COL_6   12
#define COL_7   4
#define COL_8   30
#define COL_9   3
#define COL_10  1
#define COL_11  0
#define COL_12  2

int Rows [NROWS] = {
  ROW_01,
  ROW_02,
  ROW_03,
  ROW_04,
  ROW_05,
  ROW_06,
  ROW_07,
  ROW_08
};

int Cols [NCOLS] = {
  COL_1,
  COL_2,
  COL_3,
  COL_4,
  COL_5,
  COL_6,
  COL_7,
  COL_8,
  COL_9,
  COL_10,
  COL_11,
  COL_12
};

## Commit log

2017-02-22 Changed to top mount USB connector
    This will make the production a lot easier
    [Keyboard.kicad_pcb, Keyboard.sch]
2017-02-22 V1.1 prototype
    Ordered as is from OSHPark and OSHStencils
    [Keyboard.kicad_pcb, Keyboard.sch]
2017-03-21 Final version 1.1
    Tested and works as expected!
    [Keyboard.kicad_pcb]
2017-04-05 Fixed Arduino sketches for v1.1 board
    Fixes issue #1
    [Psion-Keyboard-Firmware.ino, ScanTheMatrix.ino, board.h]
2018-06-07 Added bootloader and script for flashing
    [Keyboard.kicad_pcb, Keyboard.sch]
2018-09-19 Updated to KiCAD 5
    [Keyboard-2018-09-19-20-23-40.sch]
2018-09-19 Restore production files
    I discovered that I had overwritten the PCB files by accident. These are restored from an older version.
    [Keyboard-2018-09-19-20-23-40.sch, Keyboard.kicad_pcb, Keyboard.sch]
2018-09-19 Convert to KiCAD 5
    Updated to KiCAD version 5, regenerated board file copper pours
    [Keyboard-2018-09-19-20-54-59.sch, Keyboard.kicad_pcb]
2018-09-21 Switched to new library names
    At least for the PCB
    [Keyboard.kicad_pcb, Keyboard.sch]
2018-09-26 Added test points
    For ICSP and USB. Keyboard connections are tested through a flex cable. LEDs are tested visually.
    [Keyboard.kicad_pcb, Keyboard.sch]
2018-09-26 Final fixes
    Re-annotation, version numbering of schematic
    [Keyboard.kicad_pcb, Keyboard.sch]
2018-09-26 Started work on test rig
    Missing 3D printed parts and correct footprints for whatever pogo pin I'd like to use
    [TestRig.kicad_pcb, TestRig.sch]
2018-10-05 Adjustments to PCB
    [Keyboard.kicad_pcb, Keyboard.sch]
2019-03-06 Version 1.22 release
    Small layout fix. ISP header changed to SMD test points.
    [Keyboard.sch]
2019-10-23 Moved old TestRig Files to v01 folder
    [Keyboard.step, PCB Jig.step, PCB_JIG.stl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]
2021-12-29 Adds working test rig
    [DUT_Socket.sch, ISP_MUX.sch, Lock v10.stl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]
2022-08-31 Version 1.3 produced
    [Keyboard.kicad_pcb, Keyboard.kicad_sch, USB-Keyboard-Adapter-BOM_JLCSMT.xlsx]
